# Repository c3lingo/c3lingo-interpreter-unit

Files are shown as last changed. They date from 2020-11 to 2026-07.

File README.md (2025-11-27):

# Conference Interpreter Unit
[c3lingo.org](https://c3lingo.org) is doing the great job of translating many talks of the Chaos Communication Congress and other CCC-related events to multiple languages.
But the required hardware for simultaneous translation is quite expensive to rent, even if it's "just" a specialized analog audio mixer.

So the idea was born to design an easy to use hardware with the special requirements of our interpreters in mind.

## Requirements
The hardware unit should deliver the native audio (stage/ hall mix) to the interpreter's headset and provide a sum of all interpreter's microphone to the input of the video streaming/ recording chain.
Mixing of the final translated audio (ducking the native audio with the translation) will be done as part of the streaming/ recording chain, so the interpreter unit should just provide the sum of all microphones.

Normally just 2 interpreters will provide one translation, but demanding talks might require 3 people.
So either 3 headphone inputs/ outputs should be provided or it must be possible to daisy-chain multiple units.

The user interface of the unit should be as simple, as possible to decrease the risk of mis-configuration.
This means, that no compressor and equalizer will be added in the input group.

General requirements:
- Line input of stage/ hall mix (native language) (XLR/ 6.3 mm balanced jack combo connector)
- 3x Microphone input (XLR) (at first just dynamic microphones)
    * VU-Meter for each input channel. (Perhaps with special color scheme: too quiet, good, too loud, clipping)
    * Fader/ Potentiometer for gain control
    * On-Air switch (on/ off position, with state LED)
    * Temporary mute button (momentary switch)
- 3x Headphone output (6.3 mm mono/ stereo (2x mono) jack)
    * Should output mix of native audio, own microphone and other translator's microphone
    * Potentiometer for output volume
    * Potentiometer for volume of own microphone in the mix
    * Potentiometer for volume of other two microphones in the mix
- Outputs:
    * Sum of all translators (XLR/ 6.3 mm balanced jack combo connector)

All inputs (besides the microphones) and outputs should:
- expect/ deliver a nominal level of +6dBu (~1.5 V RMS/ 4.3 V (p-p), german TV broadcast standard, 0 dBu = 0.775 V RMS)
- be transformer balanced and galvanically isolated

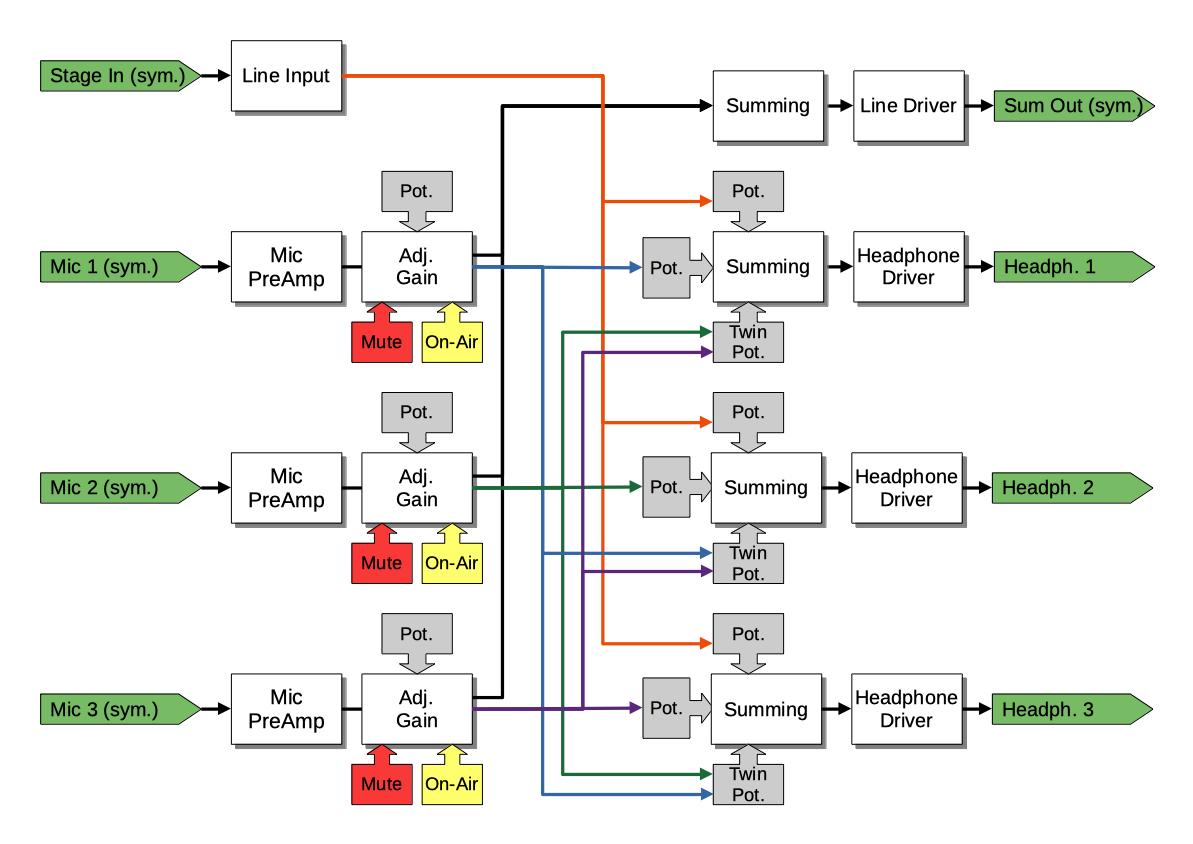
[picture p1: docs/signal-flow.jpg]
This results in a signal flow like this: 

## Status

### Tasks
- [x] Requirements collection
- [x] Electrical design draft/ proof of concept (breadboard)
- [x] Proof of concept validation
- [x] First PCB layout (prototyping modules)
- [x] More testing/ validation
- [x] Second PCB layout + casing prototype
    * [x] Channel strip schematic and PCB design
    * [x] Line I/O schematic and PCB design
    * [x] Power supply
- [x] More testing/ validation

Help is always appreciated!

### Implemented Requirements
- [x] Microphone input
- [x] Line input
- [x] Microphone summing and line output driver
- [x] Adjustable headphone mix and output volume
- [ ] ESD protection of line inputs and outputs
- [x] VU meter (own PCB)
- [x] VU meter (integrated in front panel PCB)
- [x] Mute and On-Air buttons

## Electrical Design
See [electrical-design.md](electrical-design.md).

Components marked as DNP (do not populate) are needed and need to be added.
The mark is just to generate the right BOM for ordering an assembled PBC with all SMD components, but no though-hole parts.

## User Interface
The user interface should enable the interpreters to adjust their microphone gain and headphone mix on their own.
Additionally, a (permanent) on/off switch, as well as a (temporary) mute button should be present.

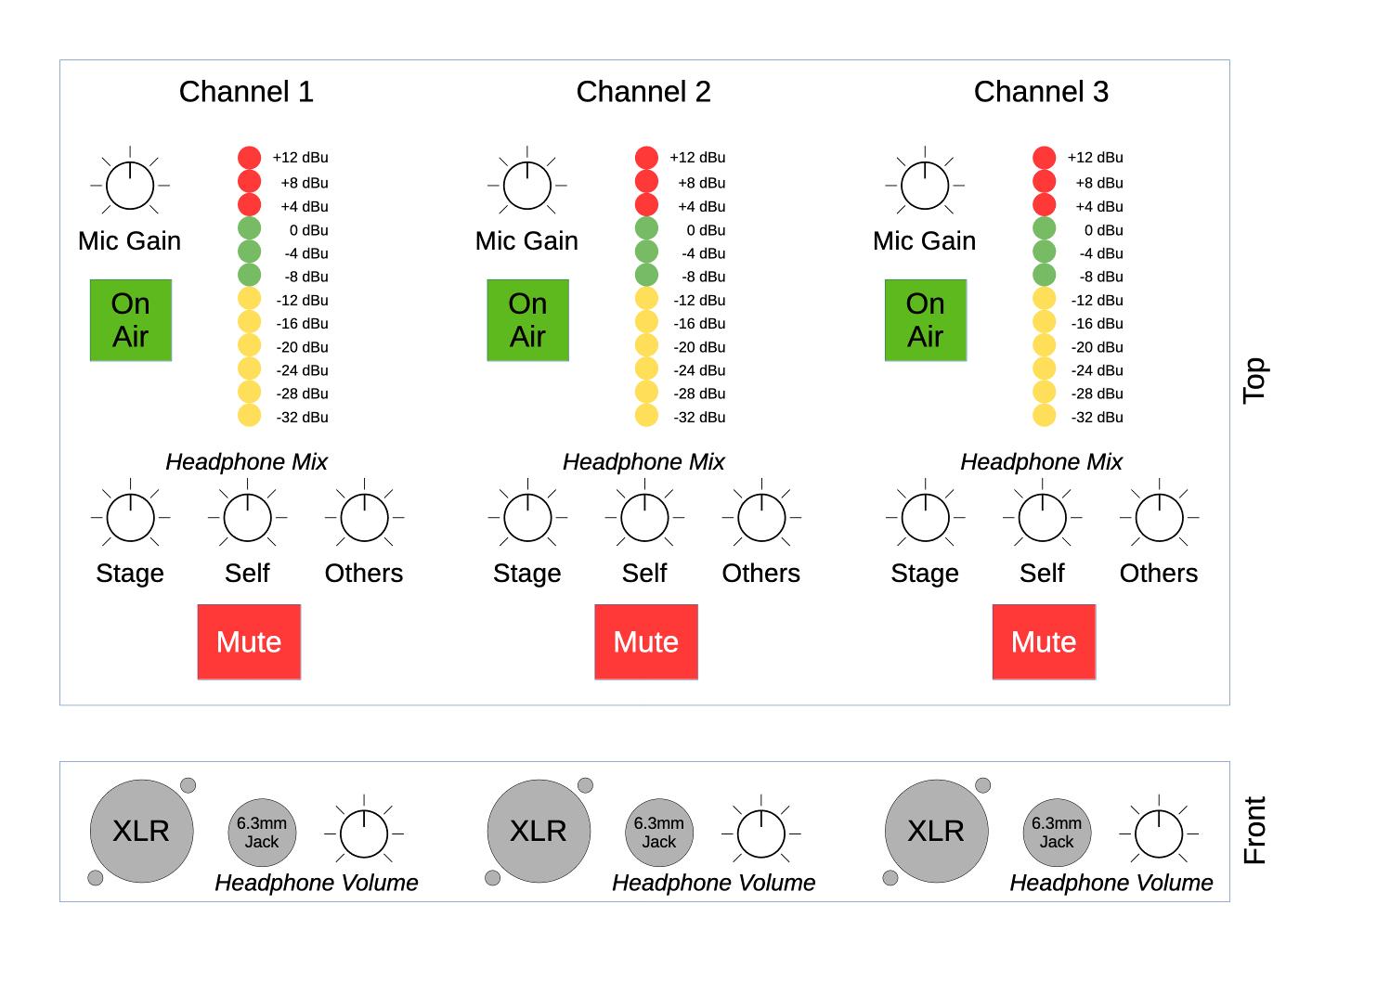
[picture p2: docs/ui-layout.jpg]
A possible UI layout might look like this: 

See [hardware-selection.md](hardware-selection.md) for the selection of potentiometers and switches.

### Casing
The casing should be a desk console (angled surface), ideally with space at the front to mount the headset ports (XLR and 6.3 mm jack).
Since it can be quite difficult to drill holes and make the appropriate cutouts on the angled surface, we designed our own housing from bent sheet metal.
See the [mechanical/](mechanical/README.md) directory for additional information.

PCBs are split up by channel and mounting surface, so that dimensional tolerancen between the surfaces are not that critical.
The top plate should have a maximum thickness of 1.5 mm, the front and back can be slightly thicker at 2 mm.
All LEDs need to be mounted with some space to the PCB surface so that they can cover the 9 mm gap to the front plate and still stick through.
A mounting guide can be found at [mechanical/assembly-helpers](mechanical/assembly-helpers/vumeter-leds.scad).

## Notes
A dynamic microphone needs at least 50-60 dB gain in the pre-amp, because a typical signal is at about 1 - 100 uV (-118 to -78 dBu or -120 to -80 dBV).

Line level in professional audio gear is at +4 dBu, which is 1.228 V (RMS).
Because 0 dBu is defined as 1 mW at a load of 600 Ohm, which needs a voltage of 0.77 V.
Increasing the voltage by a factor of 10 is an amplification of 20 dB.

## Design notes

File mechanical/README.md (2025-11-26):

# Housing and 3D Printed Parts

## Housing
The housing is made from bend sheet metal and designed in FreeCAD.

### Requirements
- FreeCAD 1.x with SheetMetal Workbench Addon installed

## Assembly Helpers
To place the level meter (aka. VU meter) LEDs at the needed height, an assembly helper is available at [./assembly-helpers/vumeter-leds.scad](./assembly-helpers/vumeter-leds.scad).

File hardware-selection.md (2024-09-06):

# c3lingo Unit -- Knobs and Switches
Detailed information why certain knobs (potentiometers) and switches were chosen.

## Potentiometers
We need some single logarithmic scale potentiometers, which are matching in size, for:

- top plate interface (all vertical style, threaded collar would be nice):
    * 1 50k single channel for the input gain
    * 3 50k single channel for the headphone mix
- front plate next to the headset jacks (horizontal style, threaded collar not needed):
    * 1 50k single channel for the headphone volume

Possible knobs may be:

- for D-style (6 mm diameter, flattened to 4.5 mm) and 18-teeth spline (6 mm diameter) axle:
    - (A) Re'an F311 series (11 mm diameter):  
        Boring: 9.0 mm D-style hole + 0.0 mm nut cover section = 9.0 mm
- for D-style (6 mm diameter, flattened to 4.5 mm) axle:
    - (B) Re'an P670 series (12 mm diameter/ 16 mm at bottom) (alt. Davies Molding 1101):  
        Boring: 7.5 mm D-style hole + 4.5 mm nut cover section = 12.0 mm  
        Nut cover: 12.9 mm diameter (M7 nut is 12.5 mm corner to corner)
    - (C) Re'an P300 series (11 mm diameter/ 15 mm at bottom):  
        Boring: 9.0 mm D-style hole + 3.0 mm nut cover section = 12.0 mm  
        Nut cover: ? mm diameter (M7 nut is 12.5 mm corner to corner)
- for 18-teeth spline (6 mm diameter) axle:
    - (D) Davies Molding 1106-A (blue)/ 1106-WA (white) (13-18 mm diameter):  
        Boring: 14.2 mm 18-teeth hole + 2.5 mm nut cover section = 16.7 mm  
        Nut cover: ? mm diameter
    - (E) Davies Molding 1101-A (11 to 16 mm diameter):  
        Boring: 8.0 mm 18-teeth hole + 4.1 mm nut cover section = 12.1 mm  
        Nut cover: ? mm diameter

Vertical (pins on bottom):

- Metal 18 teeth style:
    - CUI Devices PTN091-V50115K1A
        * 7.4 mm mounting height
        * M7x0.75 thread, 5 mm high
        * 15 mm (incl. collar thread) long 18-teeth 6 mm diameter knurled shaft with slit
        * A-taper (log) 50k
        * Datasheet: https://www.cuidevices.com/product/resource/ptn09x.pdf
        * Knobs (see above): _D_
    - Alpha RD901F-40-15K-A50K https://www.taydaelectronics.com/potentiometer-variable-resistors/rotary-potentiometer/logarithmic/50k-ohm-logarithmic-taper-potentiometer-knurled-plastic-spline-sha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
        * 10 mm mounting height
        * M9x0.75 or M7x0.75 thread, 5 mm high?
        * 15 mm (incl. collar thread) long 18-teeth 6 mm diameter knurled shaft with slit
        * A-taper (log) 50k
        * Datasheet: https://www.taiwanalpha.com/downloads?target=products&id=113
        * Notes: Hard to get
    - Bourns PTV09A-4020S-A503
        * 8.0 mm mounting height
        * no collar/ threads
        * 12 mm long 18-teeth 6 mm diameter knurled shaft with slit
        * A-taper (log) 50k
        * Datasheet: https://www.bourns.com/docs/Product-Datasheets/PTV09.pdf
- D-type shaft:
    - Bourns PTV09A-4015F-A503
        * 8.0 mm mounting height
        * no collar/ threads
        * 7 mm long D-style 6 mm diameter shaft (6 mm of which flattened)
        * A-taper (log) 50k
        * Datasheet: https://www.bourns.com/docs/Product-Datasheets/PTV09.pdf
    - Bourns PTV111-4420A-A503
        * 8.5 mm mounting height
        * no collar/ threads
        * 12 mm long D-style 6 mm diameter shaft (7 mm of which flattened)
        * A-taper (log) 50k
        * Datasheet: https://www.bourns.com/docs/Product-Datasheets/PTVPTT.pdf

Horizontal (shaft to the side):

- D-type shaft:
    - Alps Alpine RK09K1110B1R:
        * axle 10 mm above PCB
        * no collar/ threads
        * 7.4 mm long D-style 6 mm diameter shaft (6 mm of which flattened)
        * A-taper (log) 50k
        * Datasheet: TODO
        * Knobs (see above): _A_

**Selection**:

- Channel Mixer (input gain and mix):
    * CUI Devices PTN091-V50115K1A + Davies Molding 1106-A
- Headphone volume:
    * RK09K1110B1R (single, 50K, 15 mm) + Re'an F311

## Switches
The **On-Air** button needs to be a latching DPDT switch (TODO: not true any more, can also be single pole), ideally with LED illumination and max. 8 mm height (PCB to front plate), like:

- E-Switch TL2230EEF140, no illumination -- 0.60 €  
    DPDT, PCB mount  
    Height: 7.0 mm + 5.5 mm plunger (2x3 mm cap terminal)  
    Cap: see APEM models
- **APEM MHPS2273 (EU version: PHAP4673), no illumination, no audible click -- 0.41 €**  
    DPDT, PCB mount  
    Height: 7.0 mm + 5.5 mm plunger (2x3 mm cap terminal)  
    Cap: U542x (11.5 mm square, 4 mm height), **U453x (9.4 mm dia., 6.65 mm height) -- 0.64 €**  
    Cap color codes: **2 Black**, 4 Grey, 5 Yellow, 6 Red

The **mute** button needs to be a momentary SPST (normally open) or SPDT push button, like:

- E-Switch TL2230OAF140, no illumination -- 0.53 €  
    DPDT, PCB mount  
    Height: 7.0 mm + 5.5 mm plunger (2x3 mm cap terminal)  
    Cap: see APEM models
- **APEM 1413NC6/ 1415NC6 -- 3.72 €**  
    SPST/ SPDT, front plate snap-in mount, solder lugs  
    Button size: 12 mm square, Color: Red (color code 6)  
    Cap: U542x (11.5 mm square, 4 mm height), **U453x (9.4 mm dia., 6.65 mm height) -- 0.64 €**  
    Cap color codes: 2 Black, 4 Grey, 5 Yellow, 6 Red  
    Depth: 13 mm + 6 mm for contacts = 19 mm
- NKK Switches LP0115C{C,M}KW01-C -- 7.91 €  
    SPDT, front plate bushing/ snap-in mount, solder lugs  
    Button size: 13.6 mm dia., Color: Red (color code C)  
    Depth: 22 mm

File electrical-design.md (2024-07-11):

# c3lingo Unit -- Electrical Design
This file contains some notes on the electrical design.
Currently just the sources of the used circuit designs.

## Microphone Input
### Preamplifier
For the microphone preamp, we are using the NE5534 low-noise opamp with a circuit design from circuitlib.com (29-balanced-microphone-preamplifier).

### Controllable Amplification
In a normal mixer, you would be able to lower the microphone's volume to zero.
But in our case we just need on/ off and some gain range to adjust for different microphones and loudness of different people.

## Line Input/ Input Module
The line input must not be amplified at all, because loudness control of the headphones is done by the headphone amplifier section.
But the differential line-level signal must be converted to a single-ended signal by the input stage.

The current design uses a LM833-N opamp to convert the balanced signal into a single ended signal and has a second LM833-N to provide some degree (+- 6 dB) of "factory" adjustment.
The second part of that circuit was taken from the circuitlib.com audio mixer tutorial (39-how-to-build-an-audio-mixer).

## Summing
Summing is needed in two places: Creating the sum of all microphones (not adjustable, fixed output gain) and for the headphone mix (one input level adjustable).
A simple summing circuit using one operational amplifier is enough for our application.

The mixer design uses inverting op-amp circuits, because they require less components and signal routing.
Normally an audio mixer should take care of adding signals in-phase, because otherwise two microphones might cancel each other out.
In our case, there are just two types of summing: All microphones for the interpreter unit's line-out and the individual headphone mixes.
Because the stage input is quite independent of the interpreter's microphones, no special phase/ inversion considerations are needed.
And the microphones connected to our unit will experience the same inversions anyways.

## Line Output Driver
Line Output conversion is done by the [DRV134](https://www.ti.com/product/DRV134) IC.

## Headphone Output Driver
The headphone output needs a maximum output power of about 100 mW and should put the mono signal on both stereo channels of the TRS jack.
For example the DT 700 Pro (250 Ohms) need about 63 mW (4 V RMS, 16 mA), which seems to be the worst required voltage of all headphones (and not actually possible at 5V supply voltage).
Since the whole channel is desinged to use 0 dBu as target, the headphone amp needs to have an amplification of up to 5.

~~For the first draft, we're using one LM386 audio power amplifier even though it has a quite high minimal amplification of factor 20.~~
A better headphone amp seems to the the TI TPA6111A2.

## VU Meter
When searching for VU meter circuits, many use the LM3916 LED bar graph driver, which already has the right scaling built in.
But this chip is obsolete and not produced any more, so we designed our own chain of comparators to drive a set of LEDs.

## Phantom Power
The cheap but still decent Superlux HMC-660 headset is known to sound quite bad with standard 48 V phantom power (which can be easily fixed by adding some resistors inside the XLR connector).
But when I bought one in April 2021, it worked just fine with 48 V and didn't really work with 12 or 15 V.
So, if phantom power should be a feature of the interpreter unit, it probably best to have standard 48 V instead of any special treatment for one special headset.

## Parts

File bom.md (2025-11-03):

# Bill of Materials

List of major components (resistors and capacitors are left out).

All prices without VAT unless otherwise noted and without discount for higher order volume.

## Power Supply
When 48V phantom power is not urgently needed, just use a Mean Well RT-50C power supply to provide +15V, -15V and +5V.
Otherwise a way to create clean 48V from one of these power rails is needed, but we want to only use dynamic microphones anyways.

## Housing
All components fit in the off-the-shelf Hammond Manufacturing 1456PH3 housing.
But drilling and routing the holes in already bent metal sheets may be difficult

### Custom Housing
The Design is based on the Hammond Manufacturing 1456PH3 with a reduced width and increased hight of the Channel I/O Section

| Count | Manufacturer + Art. No. | Description | Distributor Order No.
|---|---|---|---
| 1 | Housing Shell | Aluminium Sheet 1.5mm | _custom made_
| 1 | Housing Bottom | Aluminium Sheet 2mm | _custom made_
| 4 | 2.9x9.5 ISO 7049 (PZ) | Self Tapping Screw (for feet) | Wegertseder 4003-317 (alt. ISO 14585 (TX) 4671-006)
| 4 | M3x10 ISO 7045 (PH) | M3x10 Pan Head Screw (alt. for feet) | Wegertseder 1118-038 (alt. ISO 14583 (TX) 3840-514)
| 4 | Rubber Feet 14x11x9mm D3  | Rubber Feet 14x11x9mm D3 | Aliexpress 1005006347586608
| 2 | PEM FH-M4-10ZI. | PEM M4 Stud 10mm | Mouser 153-FH-M4-10ZI, eBay
| 2 | Wegertseder 1776-794 | M4 Kontaktscheibe (for grounding) | Wegertseder 1776-794
| 2 | M4 DIN 6923 | M4 Hex Nut with toothed Flange (gnd.) | Wegertseder 3995-101
| 3 | _generic_ | Ring Cable Lug 0.75 mm2 (for grounding) | Voelkner D28838
| 2 | M3x5 ISO 7380 | M3x5 Flat Head Screw (for power supply) | Wegertseder 2570-578
| 2 | M3x10 ISO 14581 (TX) | M3x10 Counter Sunk Screw (for C14 socket) | Wegertseder 4663-108 (alt. ISO 7046 (PZ) 4456-239)
| 2 | M3 DIN 934 | M3 Nut (for C14 socket) | Wegertseder 2888-006

## Boards
The PCBs with all SMD components cost about 40€ per console (depending on order volume and shipping option).
Additional components like power supply, connectors, etc. add up to about 100€ per console.

### Line I/O Board Components
BOM for one PCB, needed 1x for whole assembly.
Electrolytic capacitors should have 25 V voltage rating, unless otherwise specified.

| Count | Manufacturer + Art. No. | Description | Distributor Order No.
|---|---|---|---
| 1 | Neutrik NCJ6FA-H | Stage Line Input | Voelkner D21915, Thomann 250931
| 1 | Neutrik NC3MAAH | Mix Line Output | Voelkner X39973, Mouser 568-NC3MAAH
| 1 | SPTAF 1/ 4-3,5-EL | PCB PowerSupply | Mouser 651-1862068
| 3 | WE WR-BHD 61201021621 | IDC socket, Interconn. to channel | Mouser 710-61201021621
| 1 | CTS 195-2MST | DIP switch vertical | Mouser 774-1952MST
| 1 | Keystone test point 5006  | TEST POINT BLK .063 | Mouser 534-5006
| 1 | Mean Well RT-50C | Power Suppy | Voelkner A246532
| 1 | TC-10475840 | IEC C14 Socket, screwed, M3, 40mm | Voelkner X960872 (alternative. D28684)
| 1 | LM833-N | Generic Op-Amp | JLC C473907 (usually ordered with PCB assembly)
| 1 | DRV135UA | Line Driver | JLC C431073 (usually ordered with PCB assembly)

#### Channel Strip Components
BOM for one PCB, needed 3x for whole assembly.
Electrolytic capacitors should have 25 V voltage rating, unless otherwise specified.

| Count | Model or Art. No. | Description | Distributor Order No.
|---|---|---|---
|  1 | Neutrik NC3FAAH2 | Microphone Input | Voelkner X39703, Mouser 568-NC3FAAH-2
|  1 | Rean NYS 216 or 216G | Headphone Output | Mouser 568-NYS216-U
|  1 | WE WR-BHD 61201021721 | Mix Interconn. to Line I/O, horiz.| Mouser 710-61201021721
|  2 | WE WR-BHD 61200821721 | Mix Interconn. w/ Ch. I/O, horiz. | Mouser 710-61200821721
|  1 | BKL 10120667 | IDC cable 8-pole, 25cm | Reichelt
|  1 | BKL 10120668 | IDC cable 10-pole, 25cm | Reichelt
|  1 | Molex 22-28-8024 | Pin header to Mute btn. , horiz.  | Mouser 538-22-28-8024
|  4 | CUI PTN091-V50115K1A | 50K log. (vert.) Heads. Mix +Gain | Mouser 179-PTN091V50115K1A
|  1 | Alps RK09K1110B1R | 50K log. (horiz.) Vol. | Mouser 688-RK09K1110B1R
|  3 | Davies Molding 1106-WA | Potentiometer Knob f. Mix (star)  | Mouser 5164-1106-WA
|  1 | Davies Molding 1108 | Potentiometer Knob f. Vol. (D) | Mouser 5164-1108
|  1 | Cliff CL170842CR (red) | Potentiometer Knob f. Gain (star) | Voelkner D71805
|  1 | APEM MHPS2273 | OnAir Switch | Mouser 642-MHPS2273
|  1 | APEM MH15 (alt. U4535) | On-Air Button yellow cap | Mouser 642-MH12
|  1 | Adafruit 3430 | Adafruit Arcade button (red) | Mouser 485-3430
|  3 | Kingbright WP113GDT | 2x5mm Rectangular LED, green | Mouser 604-WP113GDT (alternative: 859-LTL-433G)
|  6 | Kingbright WP113YDT | 2x5mm Rectangular LED, yellow | Mouser 604-WP113YDT (alternative: 859-LTL-433Y)
|  3 | Kingbright WP113IDT | 2x5mm Rectangular LED, red | Mouser 604-WP113IDT (alternative: 859-LTL-433HR)
| 12 | Fischer RAH 504 | 4mm spacer, square | Reichelt FIS RAH 504
|  1 | Kingbright WP710A10LID | 3mm diffused LED, red | Mouser 604-WP710A10LID
|  1 | Fischer MAH 308 | 8mm spacer, 3mm round | Reichelt FIS MAH 308
|  3 | LM339 | Quad Diff. Comparators | JLC C7948 (usually ordered with PCB assembly)
|  1 | LM833-N | Generic Op-Amp | JLC C473907 (usually ordered with PCB assembly)
|  1 | NE5534 | Low-noise bipolar Op-Amp | JLC C9916 (usually ordered with PCB assembly)
|  1 | TL072{C,I,HI}DR | Low-noise FET Op-Amp | JLC C67473 (usually ordered with PCB assembly)
|  1 | TPA6111A2 | Headphone Amp | JLC C497472 (usually ordered with PCB assembly)
|  7 | 1N4148 | Signal Diode SOD-123 | JLC C7420318 (usually ordered with PCB assembly)
|  1 | J113 | SMD J-FET SOT-23 | JLC C891686 (usually ordered with PCB assembly)

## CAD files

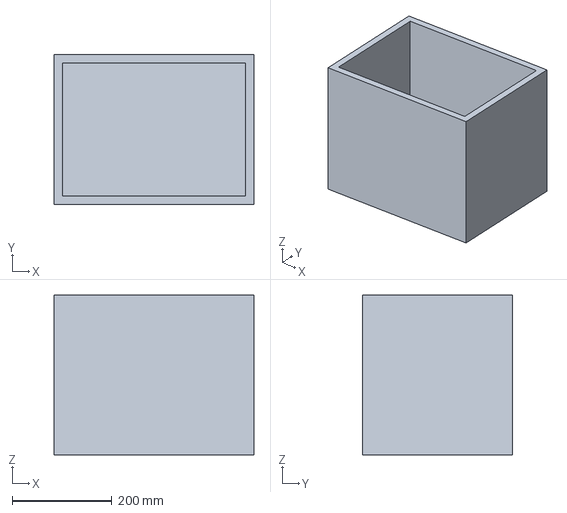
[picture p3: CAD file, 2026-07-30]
crate.FCStd
400.0 x 300.0 x 320.0 mm

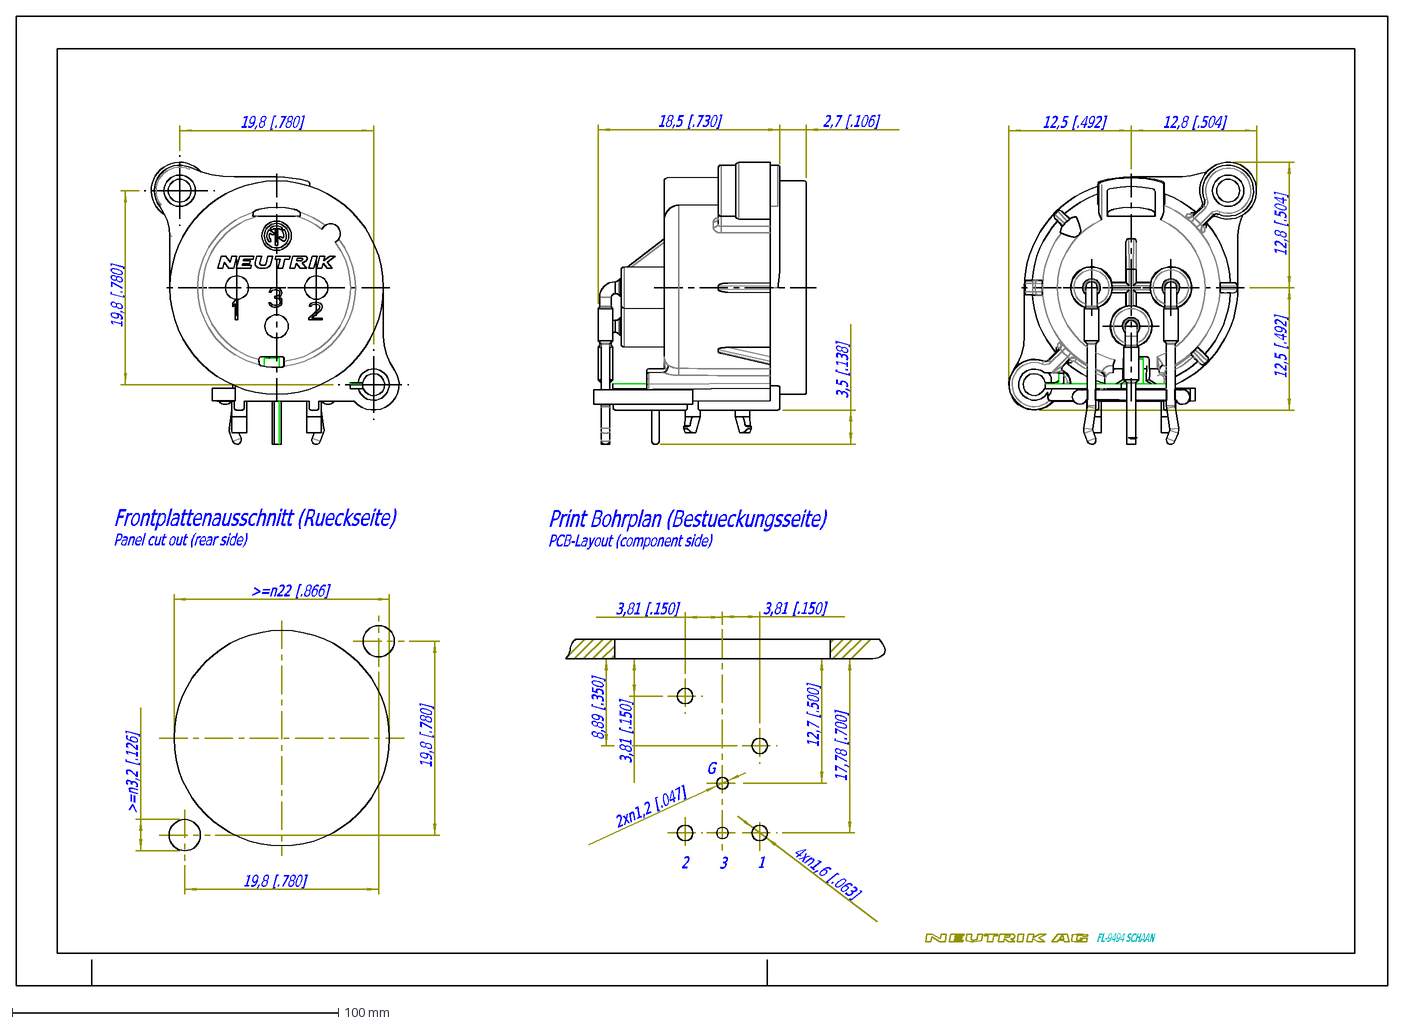
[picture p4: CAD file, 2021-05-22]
docs/datasheets/Neutrik-nc3maah.dxf
FL-9494 SCHAAN
19,8 [.780]
12,5 [.492]
3,5 [.138]
3,81 [.150]
8,89 [.350]
12,7 [.500]
17,78 [.700]
2,7 [.106]
12,8 [.504]
18,5 [.730]
Frontplattenausschnitt (Rueckseite) Panel cut out (rear side)
G
2
3
1
Print Bohrplan (Bestueckungsseite) PCB-Layout (component side)

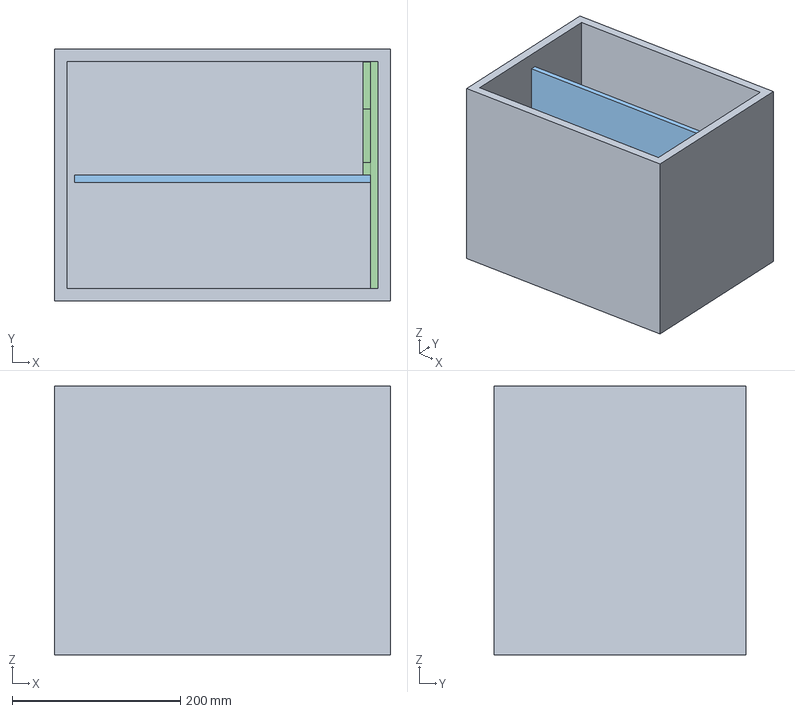
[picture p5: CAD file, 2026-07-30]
mechanical/eurocrate-inlay.FCStd
400.0 x 300.0 x 320.0 mm
Auer ED 4332
Side
Divider
Rails

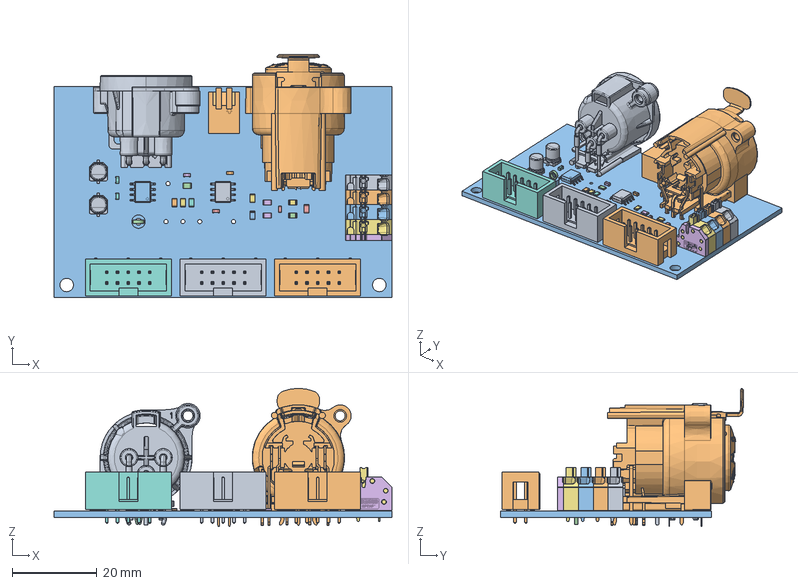
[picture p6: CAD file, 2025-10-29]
mechanical/pcba-3d/c3lingo_unit-mix_io.FCStd
80.0 x 57.6 x 32.8 mm
Jack_XLR_Neutrik_NC3MAAH_Horizontal
Jack_XLR-6.35mm_Neutrik_NCJ6FA-H_Horizontal
Bohrloch.1.1
Bohrloch.1.002
Bohrloch.2
Bohrloch.003
Bohrloch.1.003
Bohrloch.004
SPTAF_1-3.5_housing
SPTAF_1-3.5_housing001
SPTAF_1-3.5_housing002
Bohrloch.005
Bohrloch.1.004
SPTAF-0-DKL.1
SPTAF_1-3.5_housing003
IDC-Header_2x05_P2.54mm_Vertical
IDC-Header_2x05_P2.54mm_Vertical001
R_0805_2012Metric
R_0805_2012Metric001
R_0805_2012Metric002
R_0805_2012Metric003
R_0805_2012Metric004
R_0805_2012Metric005
C_0603_1608Metric
SOIC-8_3.9x4.9mm_P1.27mm
IDC-Header_2x05_P2.54mm_Vertical002
SOIC-8_3.9x4.9mm_P1.27mm001
R_0805_2012Metric006
C_0603_1608Metric001
R_0805_2012Metric007
R_0805_2012Metric008
C_0603_1608Metric002
CP_Elec_4x5.4
C_0603_1608Metric003
TestPoint_Keystone_5005-5009_Compact
TestPoint_Keystone_5005-5009_Compact001
C_0603_1608Metric004
C_0603_1608Metric005
R_0805_2012Metric009
R_0805_2012Metric010
CP_Elec_4x5.005
SW_DIP_SPSTx02_Piano_CTS_Series194-2MSTN_W7.62mm_P2.54mm
c3lingo_unit-mix_io_PCB

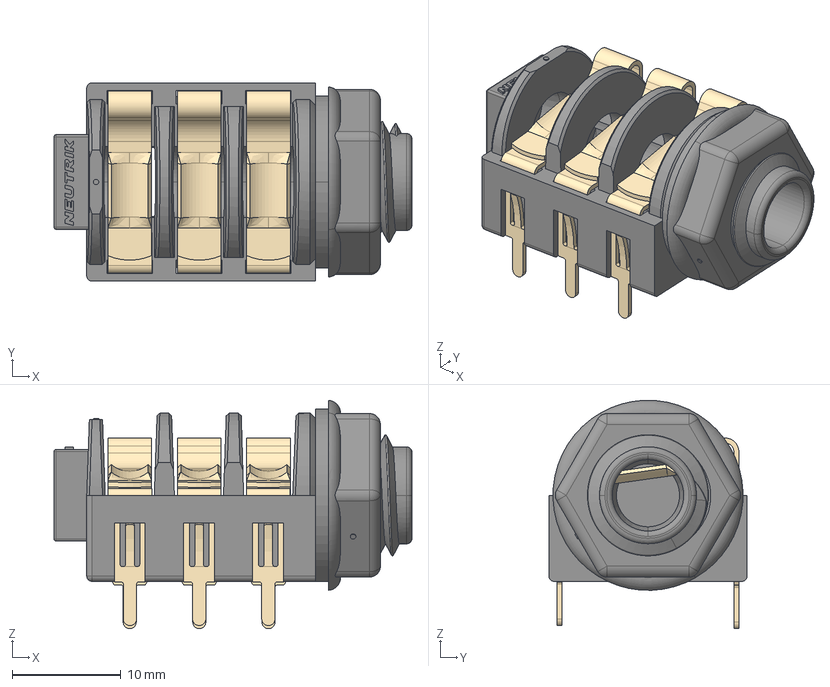
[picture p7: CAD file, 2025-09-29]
schematics/c3lingo_unit-assembly/kicad-libraries/c3lingo_unit-3dmodels/Jack_6.35mm_Neutrik_NMJ6HFD2_Horizontal.step
32.9 x 18.2 x 21.0 mm

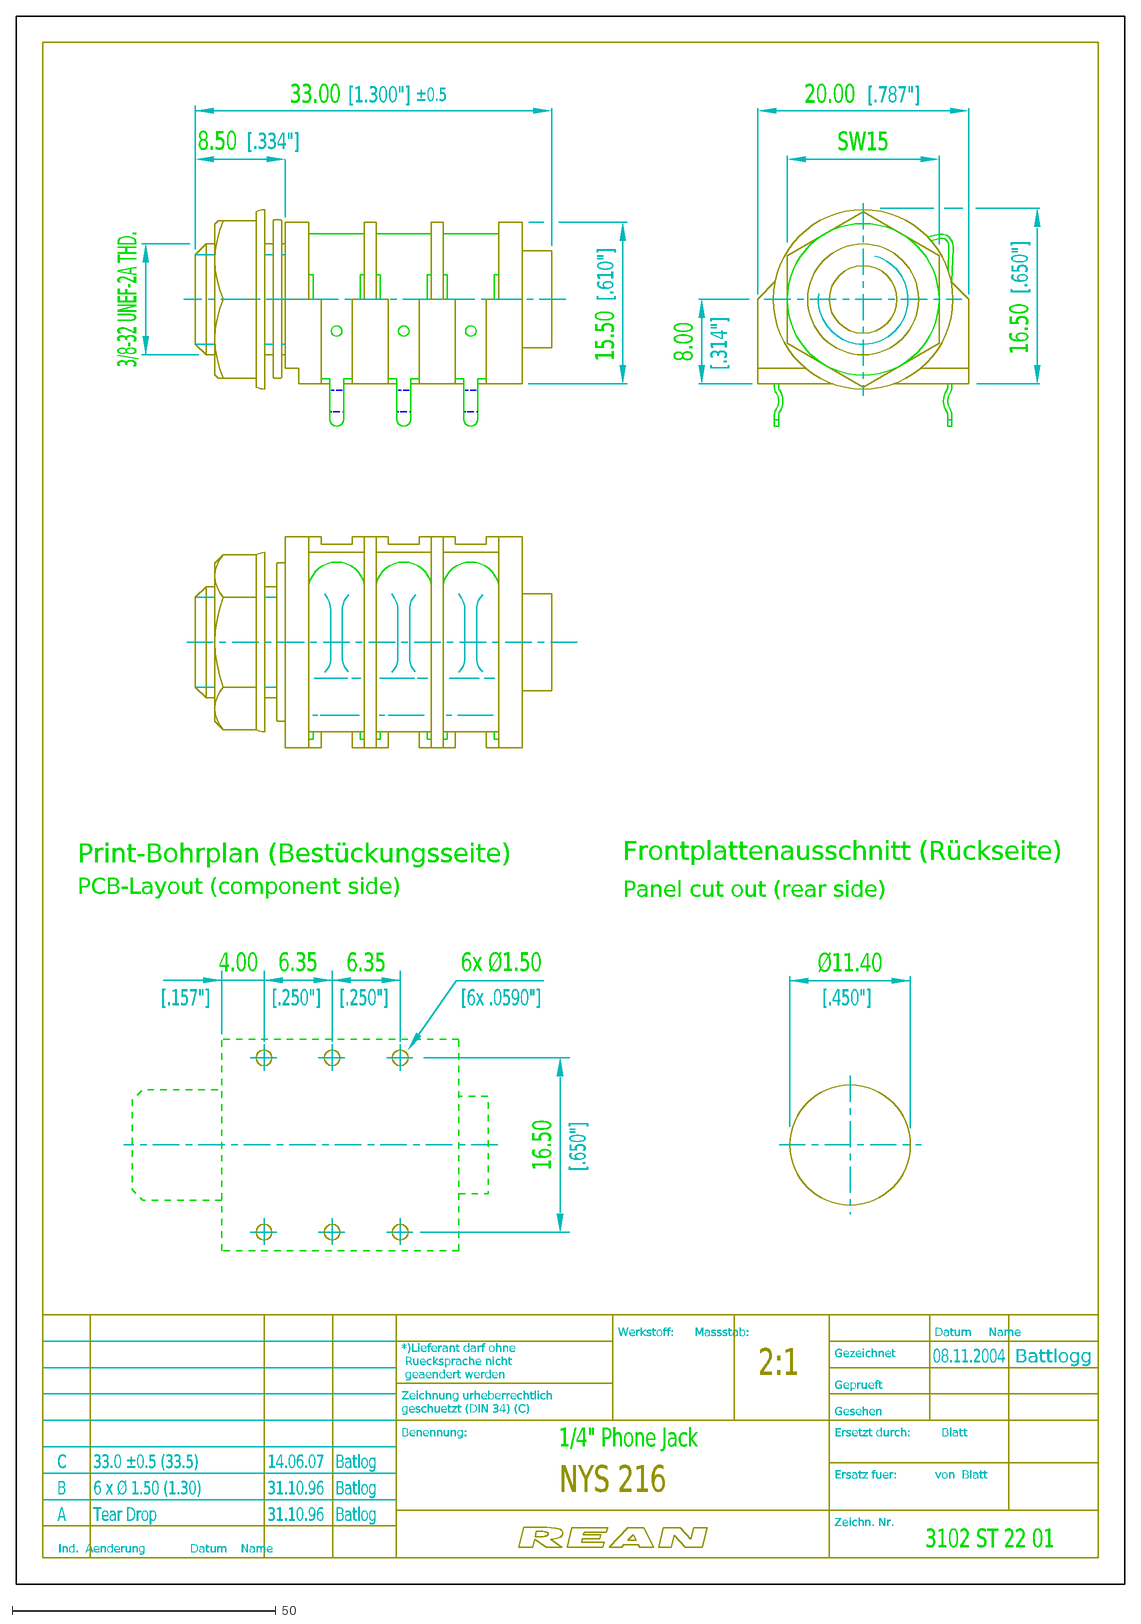
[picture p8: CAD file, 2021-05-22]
docs/datasheets/NeutrikRean-nys216.dxf
8.50
33.00
20.00
8.00
15.50
3/8-32 UNEF-2A THD.
[1.300"]
[.334"]
[.787"]
[.314"]
[.610"]
[.650"]
16.50
6.35
[.250"]
[.157"]
4.00
[6x .0590"]
6x Ø1.50
Ø11.40
[.450"]
SW15
PCB-Layout (component side)
Print-Bohrplan (Bestückungsseite)
Panel cut out (rear side)
Frontplattenausschnitt (Rückseite)
Battlogg
08.11.2004
NYS 216
1/4" Phone Jack
3102 ST 22 01
2:1
A
Tear Drop
31.10.96
Batlog
B
6 x Ø 1.50 (1.30)
C
33.0 ±0.5 (33.5)
14.06.07
Zeichn. Nr.
Ersetzt durch: Blatt
Gezeichnet
Gesehen
Datum Name
Werkstoff: Massstab:
Benennung:
*)Lieferant darf ohne
Ruecksprache nicht
geaendert werden
Zeichnung urheberrechtlich
geschuetzt (DIN 34) (C)
Geprueft
Ersatz fuer: von Blatt
Ind. Aenderung Datum Name
±0.5

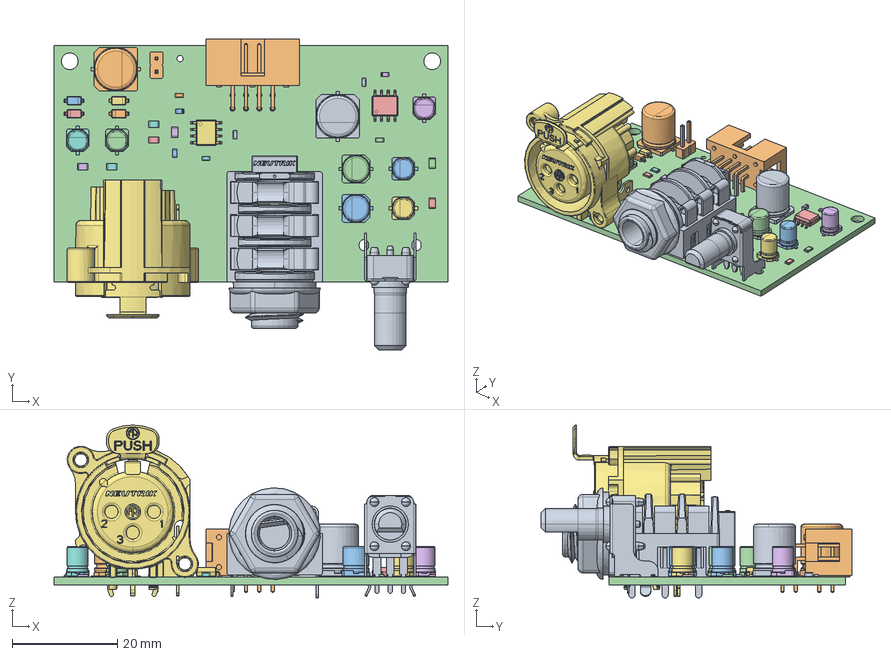
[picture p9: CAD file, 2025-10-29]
mechanical/pcba-3d/c3lingo_unit-channel_io.FCStd
75.0 x 59.2 x 32.9 mm
Jack_6.35mm_Neutrik_NMJ6HFD2_Horizontal
C_0603_1608Metric
D_SOD-123
CP_Elec_4x5.8
R_0805_2012Metric
R_0805_2012Metric001
SOIC-8_3.9x4.9mm_P1.27mm
R_0805_2012Metric002
C_0603_1608Metric001
IDC-Header_2x04_P2.54mm_Horizontal
CP_Elec_4x5.009
R_0603_1608Metric
SOIC-8_3.9x4.9mm_P1.27mm001
CP_Elec_4x5.010
Jack_XLR_Neutrik_NC3FAAH2_Horizontal
C_0603_1608Metric002
Potentiometer_Alps_RK09K_Single_Horizontal
D_SOD-124
R_0603_1608Metric001
R_0805_2012Metric003
R_0805_2012Metric004
R_0805_2012Metric005
D_SOD-125
CP_Elec_4x5.011
CP_Elec_8x10
CP_Elec_8x011
R_0603_1608Metric002
CP_Elec_5x5.8
D_SOD-126
R_0603_1608Metric003
CP_Elec_4x5.012
R_0805_2012Metric006
C_0603_1608Metric003
PinHeader_1x02_P2.54mm_Vertical
CP_Elec_5x5.009
c3lingo_unit-channel_io_PCB

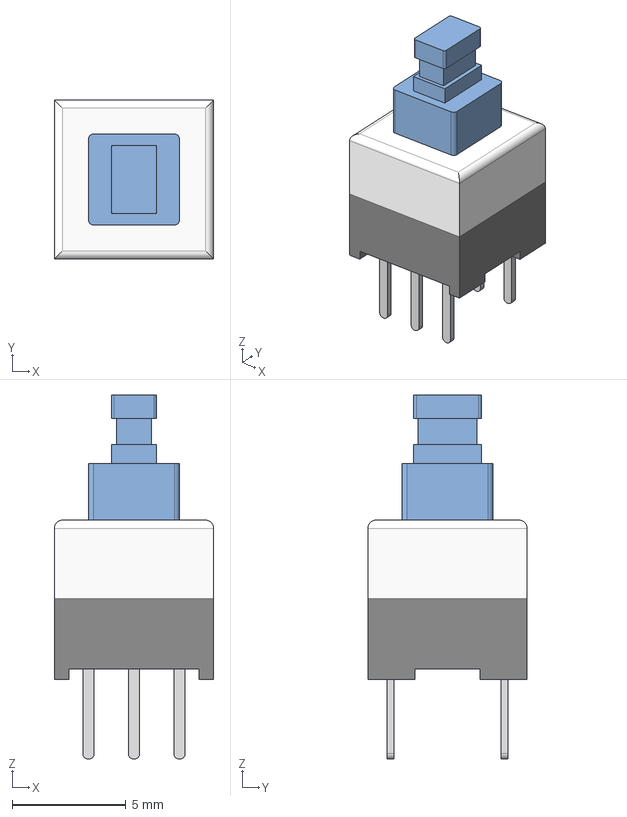
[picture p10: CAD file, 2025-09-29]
schematics/c3lingo_unit-assembly/kicad-libraries/c3lingo_unit-3dmodels/SW_APEM_MHPS2273_DPDT.step
7.00 x 7.00 x 16.0 mm

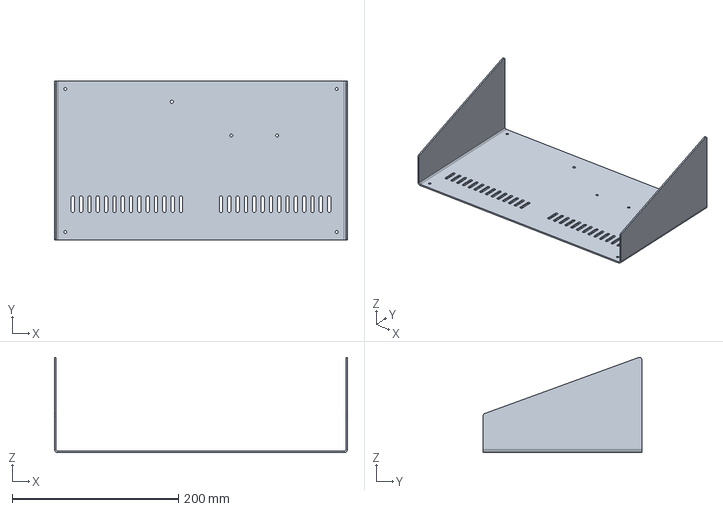
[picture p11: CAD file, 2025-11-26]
mechanical/c3lingo-interpreter-unit_housing_bottom.FCStd
352.0 x 191.0 x 114.5 mm

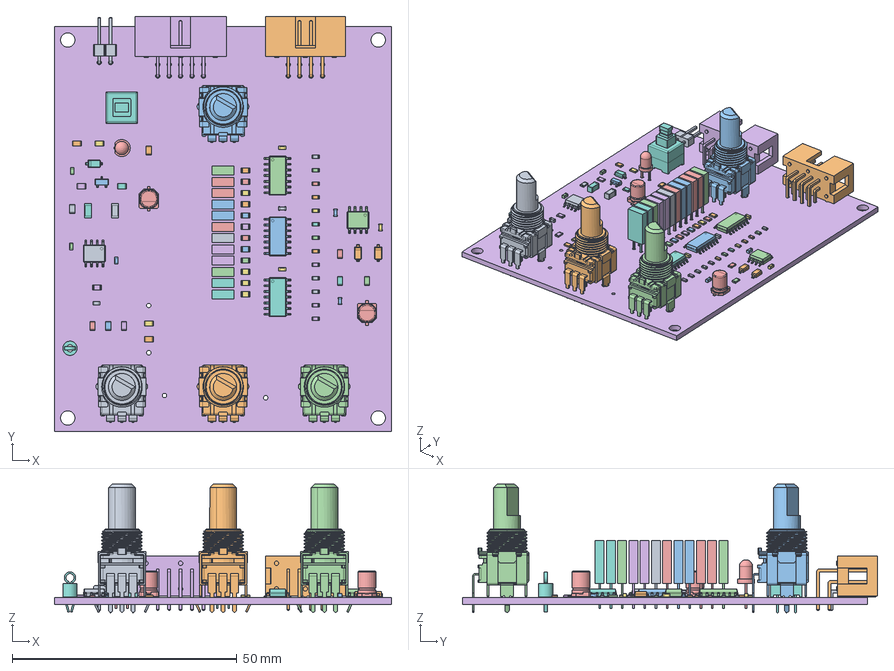
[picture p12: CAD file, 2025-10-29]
mechanical/pcba-3d/c3lingo_unit-channel_mixer.FCStd
75.0 x 92.2 x 28.6 mm
Potentiometer_Alps_RK09L1140_Single_Vertical
Potentiometer_Alps_RK09L1140_Single_Vertical001
Potentiometer_Alps_RK09L1140_Single_Vertical002
Potentiometer_Alps_RK09L1140_Single_Vertical003
LED_D3.0mm
IDC-Header_2x05_P2.54mm_Horizontal
R_0805_2012Metric
SW_APEM_MHPS2273_DPDT
R_0603_1608Metric
R_0805_2012Metric001
C_0603_1608Metric
C_0603_1608Metric001
R_0805_2012Metric002
R_0805_2012Metric003
R_0805_2012Metric004
TestPoint_Keystone_5005-5009_Compact
R_0805_2012Metric005
D_SOD-123
C_0603_1608Metric002
R_0603_1608Metric001
LED_Rectangular_W5.0mm_H2.0mm
R_0805_2012Metric006
C_0603_1608Metric003
LED_Rectangular_W5.0mm_H2.0mm001
C_0603_1608Metric004
R_0805_2012Metric007
SOIC-14_3.9x8.7mm_P1.27mm
LED_Rectangular_W5.0mm_H2.0mm002
LED_Rectangular_W5.0mm_H2.0mm003
LED_Rectangular_W5.0mm_H2.0mm004
R_0805_2012Metric008
R_0805_2012Metric009
R_0603_1608Metric002
R_0603_1608Metric003
LED_Rectangular_W5.0mm_H2.0mm005
C_0603_1608Metric005
R_0805_2012Metric010
LED_Rectangular_W5.0mm_H2.0mm006
C_0603_1608Metric006
LED_Rectangular_W5.0mm_H2.0mm007
PinHeader_1x02_P2.54mm_Horizontal
R_0805_2012Metric011
LED_Rectangular_W5.0mm_H2.0mm008
SOIC-8_3.9x4.9mm_P1.27mm
CP_Elec_4x5.8
R_0603_1608Metric004
R_0603_1608Metric005
C_1206_3216Metric
C_1206_3216Metric001
D_SOD-124
C_0603_1608Metric007
R_0603_1608Metric006
R_0805_2012Metric012
R_0805_2012Metric013
R_0805_2012Metric014
R_0805_2012Metric015
LED_Rectangular_W5.0mm_H2.0mm009
R_0805_2012Metric016
R_0805_2012Metric017
LED_Rectangular_W5.0mm_H2.0mm010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

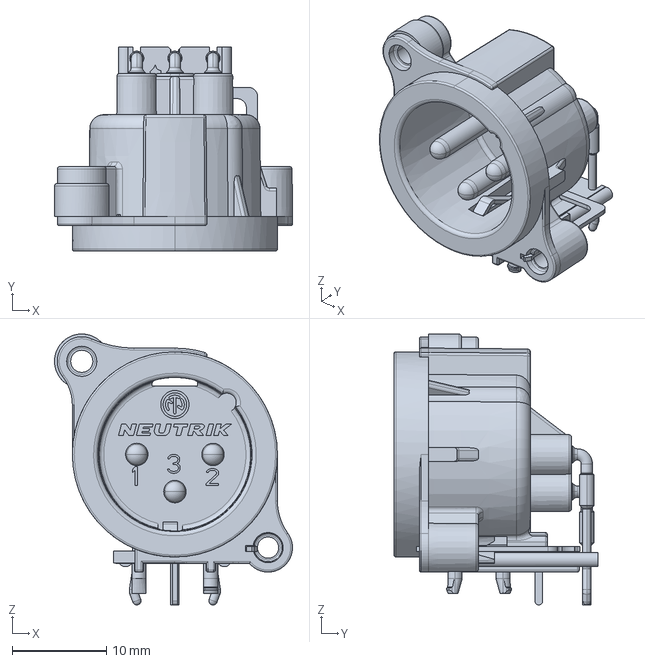
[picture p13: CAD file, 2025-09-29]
schematics/c3lingo_unit-assembly/kicad-libraries/c3lingo_unit-3dmodels/Jack_XLR_Neutrik_NC3MAAH_Horizontal.step
25.3 x 21.7 x 28.8 mm

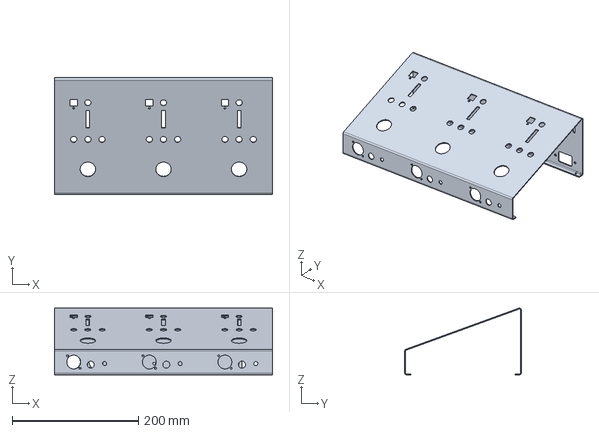
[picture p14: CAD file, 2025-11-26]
mechanical/c3lingo-interpreter-unit_housing_shell.FCStd
346.0 x 185.0 x 106.0 mm

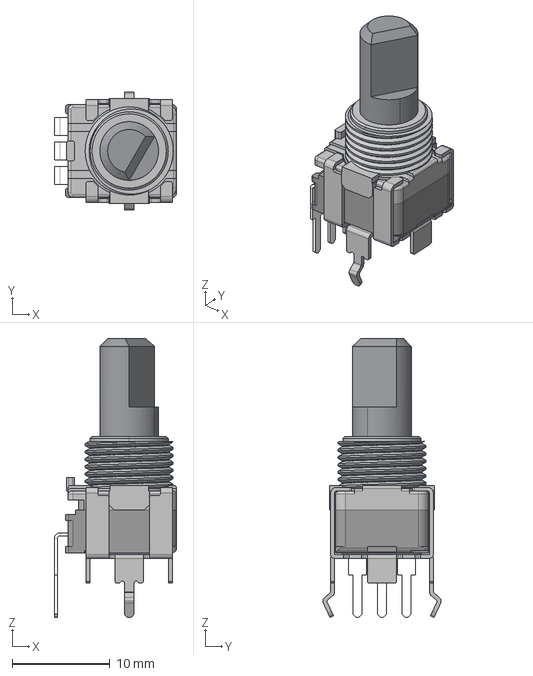
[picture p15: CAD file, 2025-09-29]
schematics/c3lingo_unit-assembly/kicad-libraries/c3lingo_unit-3dmodels/Potentiometer_Alps_RK09L1140_Single_Vertical.step
12.5 x 12.1 x 28.5 mm

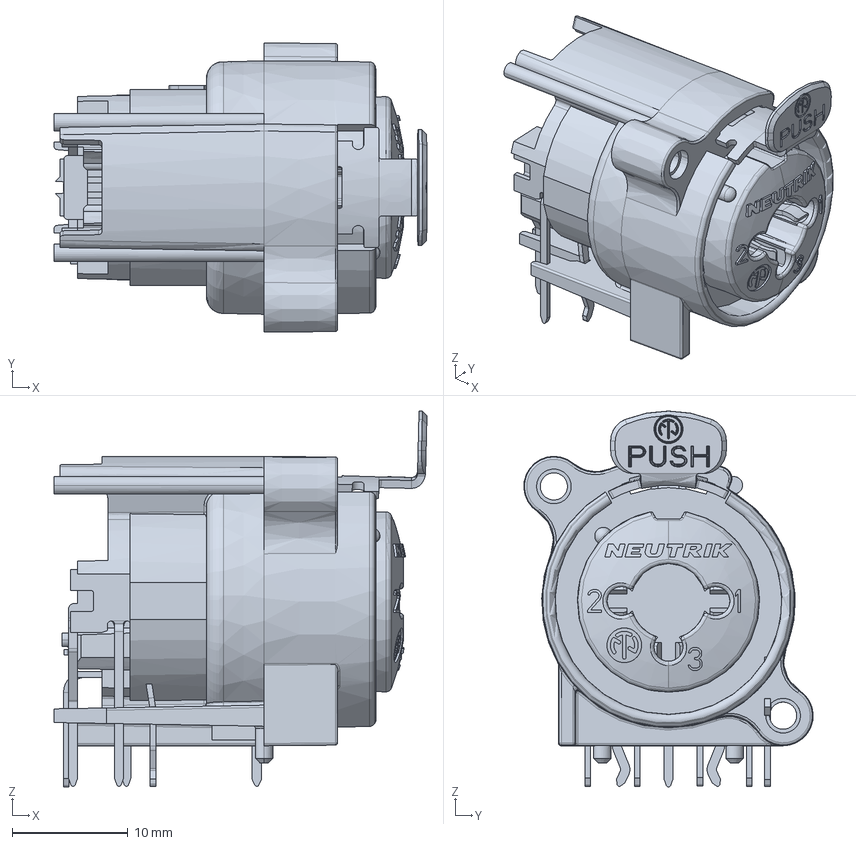
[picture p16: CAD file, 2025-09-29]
schematics/c3lingo_unit-assembly/kicad-libraries/c3lingo_unit-3dmodels/Jack_XLR-6.35mm_Neutrik_NCJ6FA-H_Horizontal.step
32.2 x 25.0 x 32.5 mm

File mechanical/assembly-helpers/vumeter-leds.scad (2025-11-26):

wall        = 2.0;
depth       = 11.5;

led_count   = 12;
led_width   = 5.5;
led_height  = 2.0;
led_space   = 0.5;

all_length = led_count*(led_height + led_space);

// main housing
difference() {
    cube([all_length + 2*wall,
      led_width + 2*wall,
      depth + wall]);
    
    translate([wall,wall,wall]) {
        // LED cutout
        cube([all_length,
              led_width,
              depth]);
        
        // resistor cutout
        cutout_depth = 1;
        cutout_diff = 0.5;
        translate([+cutout_diff/2,led_width,depth-cutout_depth]) {
            cube([all_length - cutout_diff, wall, cutout_depth]);
        }
        
        // capacitor cutout
        cutout_len = 3.5;
        cutout_offset = 0.8;
        translate([all_length,((led_width-cutout_len)/2+cutout_offset),depth-cutout_depth]) {
            cube([wall, cutout_len, cutout_depth]);
        }
    }
}

// ribs
rib_gap = 0.2;
rib_height = 2.5;
translate([wall+led_height+(rib_gap/2)+(led_space/2), wall, wall]){
    for (i = [0 : 1 : (led_count-2)]) {
        translate([i*(led_height+led_space), 0, 0]){
            cube([led_space - rib_gap, led_width, rib_height]);
        }
    }
}

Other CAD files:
mechanical/c3lingo-interpreter-unit_housing.FCStd
mechanical/c3lingo-interpreter-unit.FCStd
schematics/c3lingo_unit-assembly/kicad-libraries/c3lingo_unit-3dmodels/Potentiometer_Alps_RK09K_Single_Horizontal.step
schematics/c3lingo_unit-assembly/kicad-libraries/c3lingo_unit-3dmodels/TerminalBlock_Phoenix_SPTAF-1-4-3.5_1x04.step

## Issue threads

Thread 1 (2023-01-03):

ESD Protection/ Galvanic Isolation

jbeyerstedt, 2023-01-03:
I have not clue on ESD protection.
What is acutally needed and how can this be achieved?

GladOSkar, 2023-01-05:
I'd typically add bidirectional TVS diodes on all inputs of my digital circuits for this, not sure how well this translates to analog though

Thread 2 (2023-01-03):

Case Design

jbeyerstedt, 2023-01-03:
To cut cost and for more fun, a custom housing might be designed. There are no special requirements on the material used for now.

But the thickess of some walls is important because of the potentiometers, buttons and connectors sticking through it:
- top plate (main UI): 1.0 to 2.0 mm
- front side (headphone jacks): 1.0 to 2.0 mm
- back side (XLR line in and out, mains supply): less than 3 mm

Please see the BoM section of the readme for the model numbers of the used connectors, potentiometers and buttons and use their data sheets for the required hole pattern.

jbeyerstedt, 2023-01-15:
Possible options:
- https://www.takachi-enclosure.com/products/TS:
    * TS20-15: 35 mm H1 (25 mm panel), 70 mm H2 (60 mm panel), 200 mm W (180 mm panel), 150 mm D
    * TS29-21: 50 mm H1 (40 mm panel), 99 mm H2 (79 mm panel), 290 mm W (270 mm panel), 210 mm D
- https://www.takachi-enclosure.com/products/CF:
    * CF28-28GS: 50 mm H1 (27 mm panel), 99 mm H2 (72 mm panel), 280 mm W (261 mm panel), 280 mm D (238 mm panel)

jbeyerstedt, 2024-09-26:
New distance between mixer PCB and front plate is about 9 mm

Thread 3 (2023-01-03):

Improve/ Extend Power Supply

jbeyerstedt, 2023-01-03:
The electrical circuit needs some voltages to work:
- +15V and -15V for op-amps (< 100 mA) and LEDs (about 100 mA max.?)
- 48V for phantom power (if this feature is wanted/ needed)

The current prototype uses an off-the-shelf power supply module (MEAN WELL RT-65C; RT-50C should work, too), which works just fine without additional filtering.
But the 48 V phantom power is still an open question. We either need to get it from the +15 V or just do a completely different power supply design. Or the phantom power feature will just be removed all together.

jbeyerstedt, 2024-07-07:
To also add 48 V phantom power to the design, it either needs to be produced by a step-up DC/DC converter (which has a quite noisy output) or **another power supply**:

- Mean Well PT-45C (+15 V @1.6 A, -15V @0.3 A, +5 V @3 A)
- Mean Well PS-05-48 (+48 V @0.11 A)

Alternately some voltages can be produced by step-down DC/DC converters.
Their output power is depending on a pending decision, if the vu meter shall be powered by 15 or 5 V:

1. vu meter on 15 V: +15 V rail needs about 6.5 W power, 5 V line 1 W
2. vu meter on 5 V:  +15 V rail needs about 2 W power, 5 V line 3 W

**Two (less oversized) switching power supplies + DC/DC converter**
- Mean Well PD-2515 (+15 V @0.8 A, -15V @0.8 A)
- Mean Well PS-05-48 (+48 V @0.11 A)
- DC/DC from 15 to 5V
  - w/o vu meter (100mA): SPA01A-05, SPAN02A-05, SLC03A-05 or SCWN03A-05
  - with vu meter (400mA): SLC03A-05, SCWN03A-05 or SCWN06A-05

**48V wall adaptor + DC/DC converters**
- Mean Well NGE30E48-P1J (48 V, 0.63 A) or GST25A48-P1J (48 V, 0.52 A)
- vu meter on 15 V:
  - DC/DC to +-15V (600mA): DKMW15G-15
  - DC/DC to 5V (100mA): SPA01A-05, SPAN02A-05, SLC03A-05 or SCWN03A-05
- vu meter on 5 V:
  - DC/DC to +-15V (100mA): DPBW03G-15 (ext. EMC req.), DLC03C-15, DCWN03C-15 or DCWN06C-15
  - DC/DC to 5V (400mA): SLC03A-05, SCWN03A-05 or SCWN06A-05

jbeyerstedt, 2024-10-26:
Options when leaving out 48V (or generating it from +15V somehow):
- Mean Well RT-50C (5V, 4A; +15V, 1.5A; -15V, 0.5A), enclosed type: ~20€ incl. VAT
- 48V wall adaptor + DC/DC (DCWN03C-15) as mentioned above: ~29€ incl. VAT

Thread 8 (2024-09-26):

Errata/ Notes on Revision 0.3.3

jbeyerstedt, 2024-09-26:
Loose collection of things which I noticed when using prototype 2 (v0.3.3) for the first time:

Positive:
- Microphone and headphones noise floor seems to be quite a lot lower than at prototype 1
- vu meter low-pass filtering is not really noticeable (I like the quite snappy response)
- It still works

To improve:
- vu meter does not reach the top LED before the microphone clips at the headphones and line output
  - TODO: Increase amplification or change reference voltages
- low-pass filter of vu meter amplifier/ rectifier has a DC offset. Lowest LED is always lit, bottom 5 LEDs when microphone is "on"
- headphones have a bit too harsh high-end for my taste
- muting delay is too long (takes about 1 second to fade down, should be more like 100 ms max)
- microphone gain might be a bit too high (1/8 turn (should be about 10 dB) is fine for SM58 and HMD660)

EDIT: More to improve:
- Replace line input trim with a 10k resistor (empirical value for 0 dBu) or just make the op-amp stage unity gain. Question: Is the op-amp stage needed at all then?
- Add some low-pass filtering on the microphone input
- Maybe: Reduce line out by 6 dB (it clips my audio interface quite easily)

jbeyerstedt, 2024-09-26:
Also: Replace line input trim with a 10k resistor (empirical value for 0 dBu) or just make the op-amp stage unity gain

jbeyerstedt, 2024-11-14:
Required rework:

- Channel Mixer:
  - Replace C314 with 100nF (less muting delay)
  - Replace C301 with 680pF (11 kHz low-pass on headphone)
  - Replace R309 with 8.2K, replace R232 with 220R, replace R335 with 18K (adjust vu meter scale to -27 to +6 dBu)
  - optional: Replace R303 with 1K (reduce microphone gain range to 34 dB instead of 45 dB)
- Channel I/O:
  - Add 220pF in parallel to R602 (10kHz low-pass on microphone to reduce high-frequency noise)

jbeyerstedt, 2024-11-16:
Remaining points (which require layout changes or more changed components) are moved to #9

Closed 2024-11-28.

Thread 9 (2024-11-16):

Fixes/ Features for next PCB revision

jbeyerstedt, 2024-11-16:
After using the second PCB revision (v0.3.3) and applying some rework, some more fixes are left for a new PCB revision:

- [ ] General: Use IDC connectors for board-to-board connections (easier to build the cables)
- [ ] Channel Mixer: Use new resistors in the reference value ladder of the microphone level meter (aka VU meter)
- [ ] Channel Mixer: Reduce adjustable microphone gain range to 34dB instead of 45dB (R303 = 1K)
- [ ] Line I/O: Remove adjustable gain on line input, maybe even completely remove the second OpAmp
- [ ] Line I/O: Reduce summing gain to -6 dB (so output is 0 dBu nominally)
- [ ] Channel Mixer: Replace SMD LEDs with 2x5 mm rectangular THD LEDs?

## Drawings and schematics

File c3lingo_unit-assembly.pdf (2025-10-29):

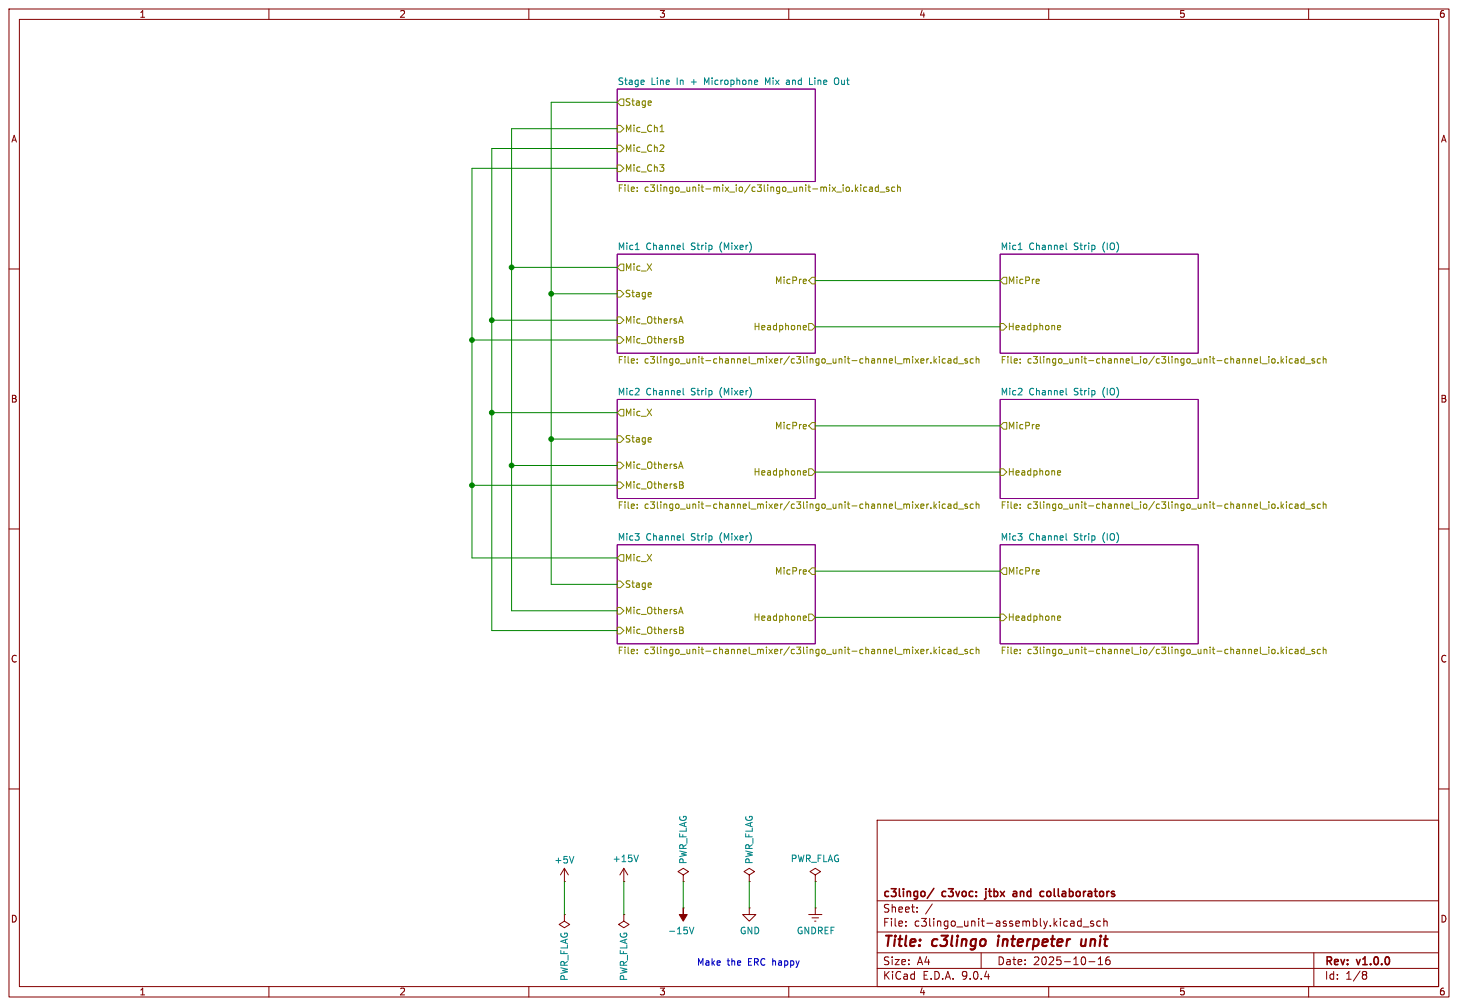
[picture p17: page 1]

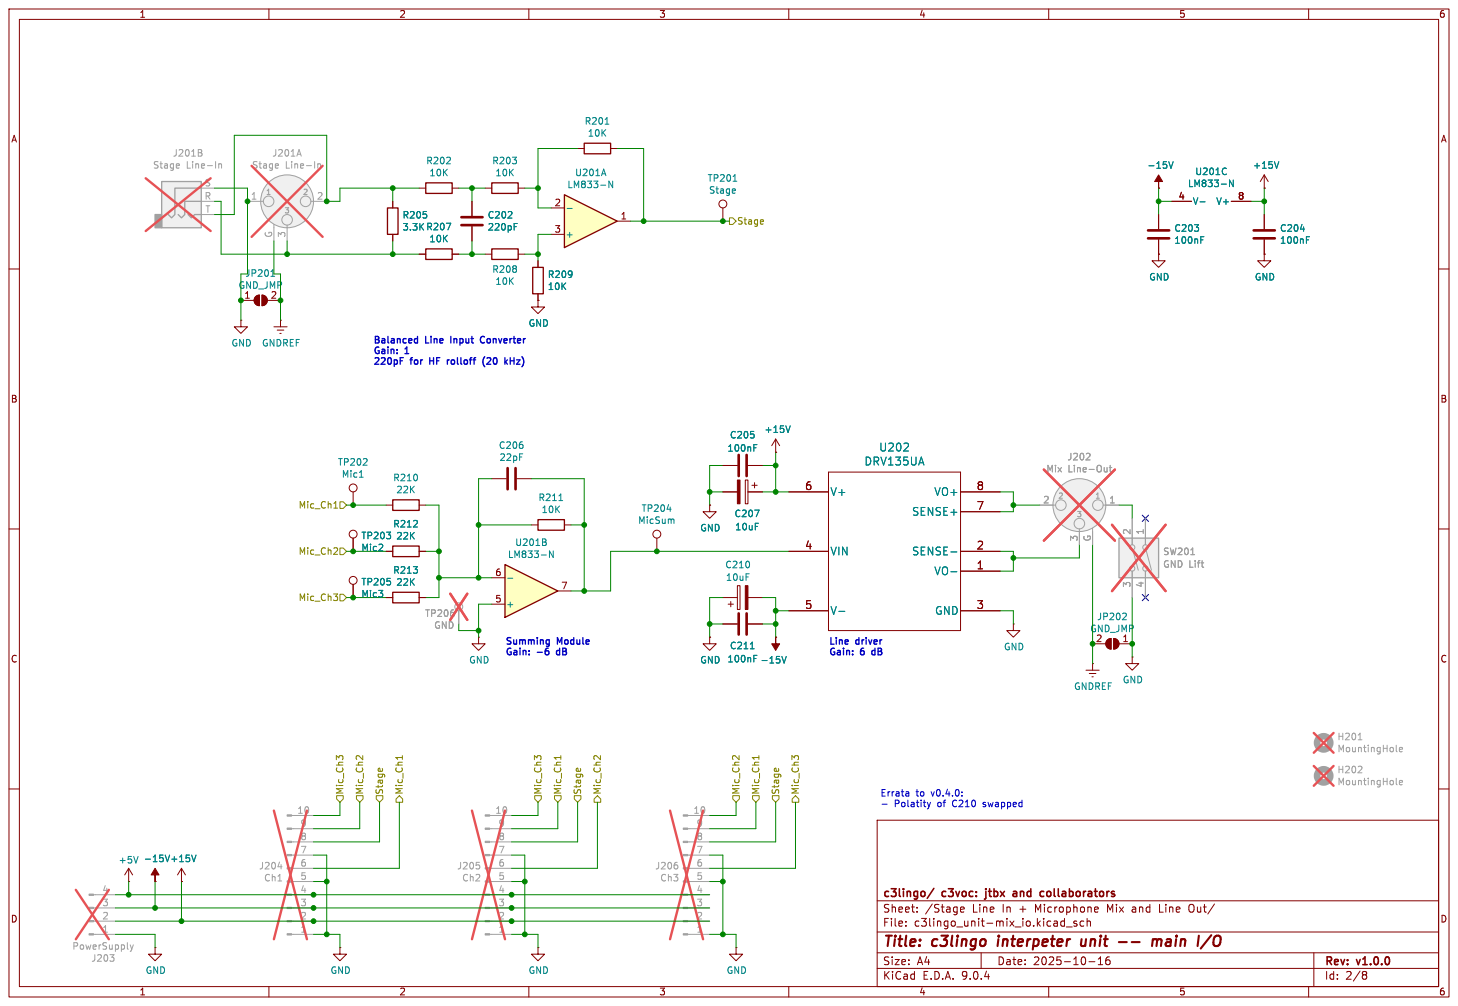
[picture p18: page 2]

Balanced Line Input Converter Gain: 1

220pF for HF rolloff (20 kHz) TP203 Mic2 TP205 Mic3 R213

4 SW201 GND Lift -15V GND GND

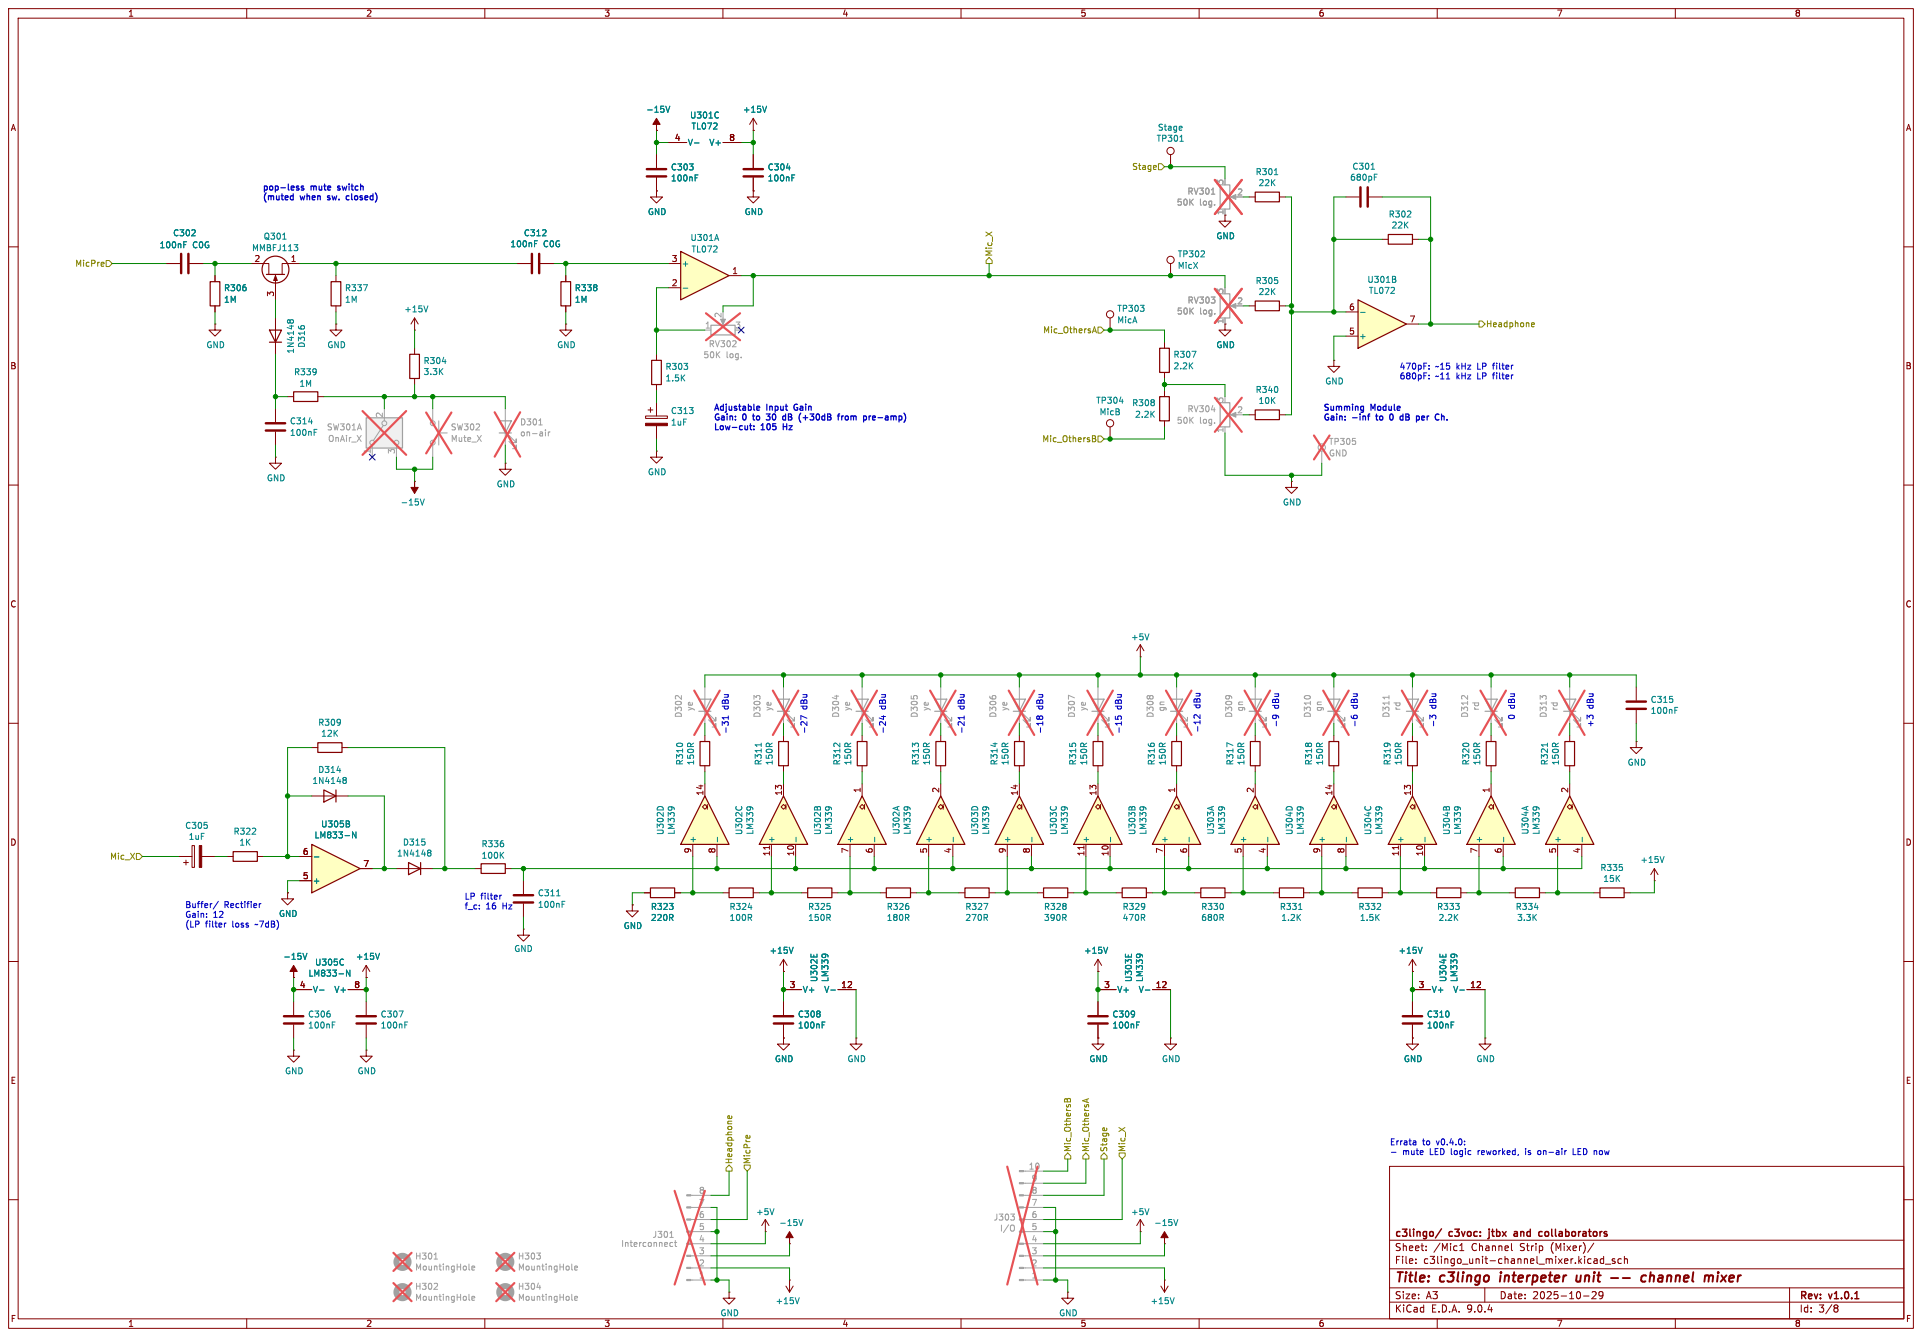
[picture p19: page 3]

(muted when sw. closed)

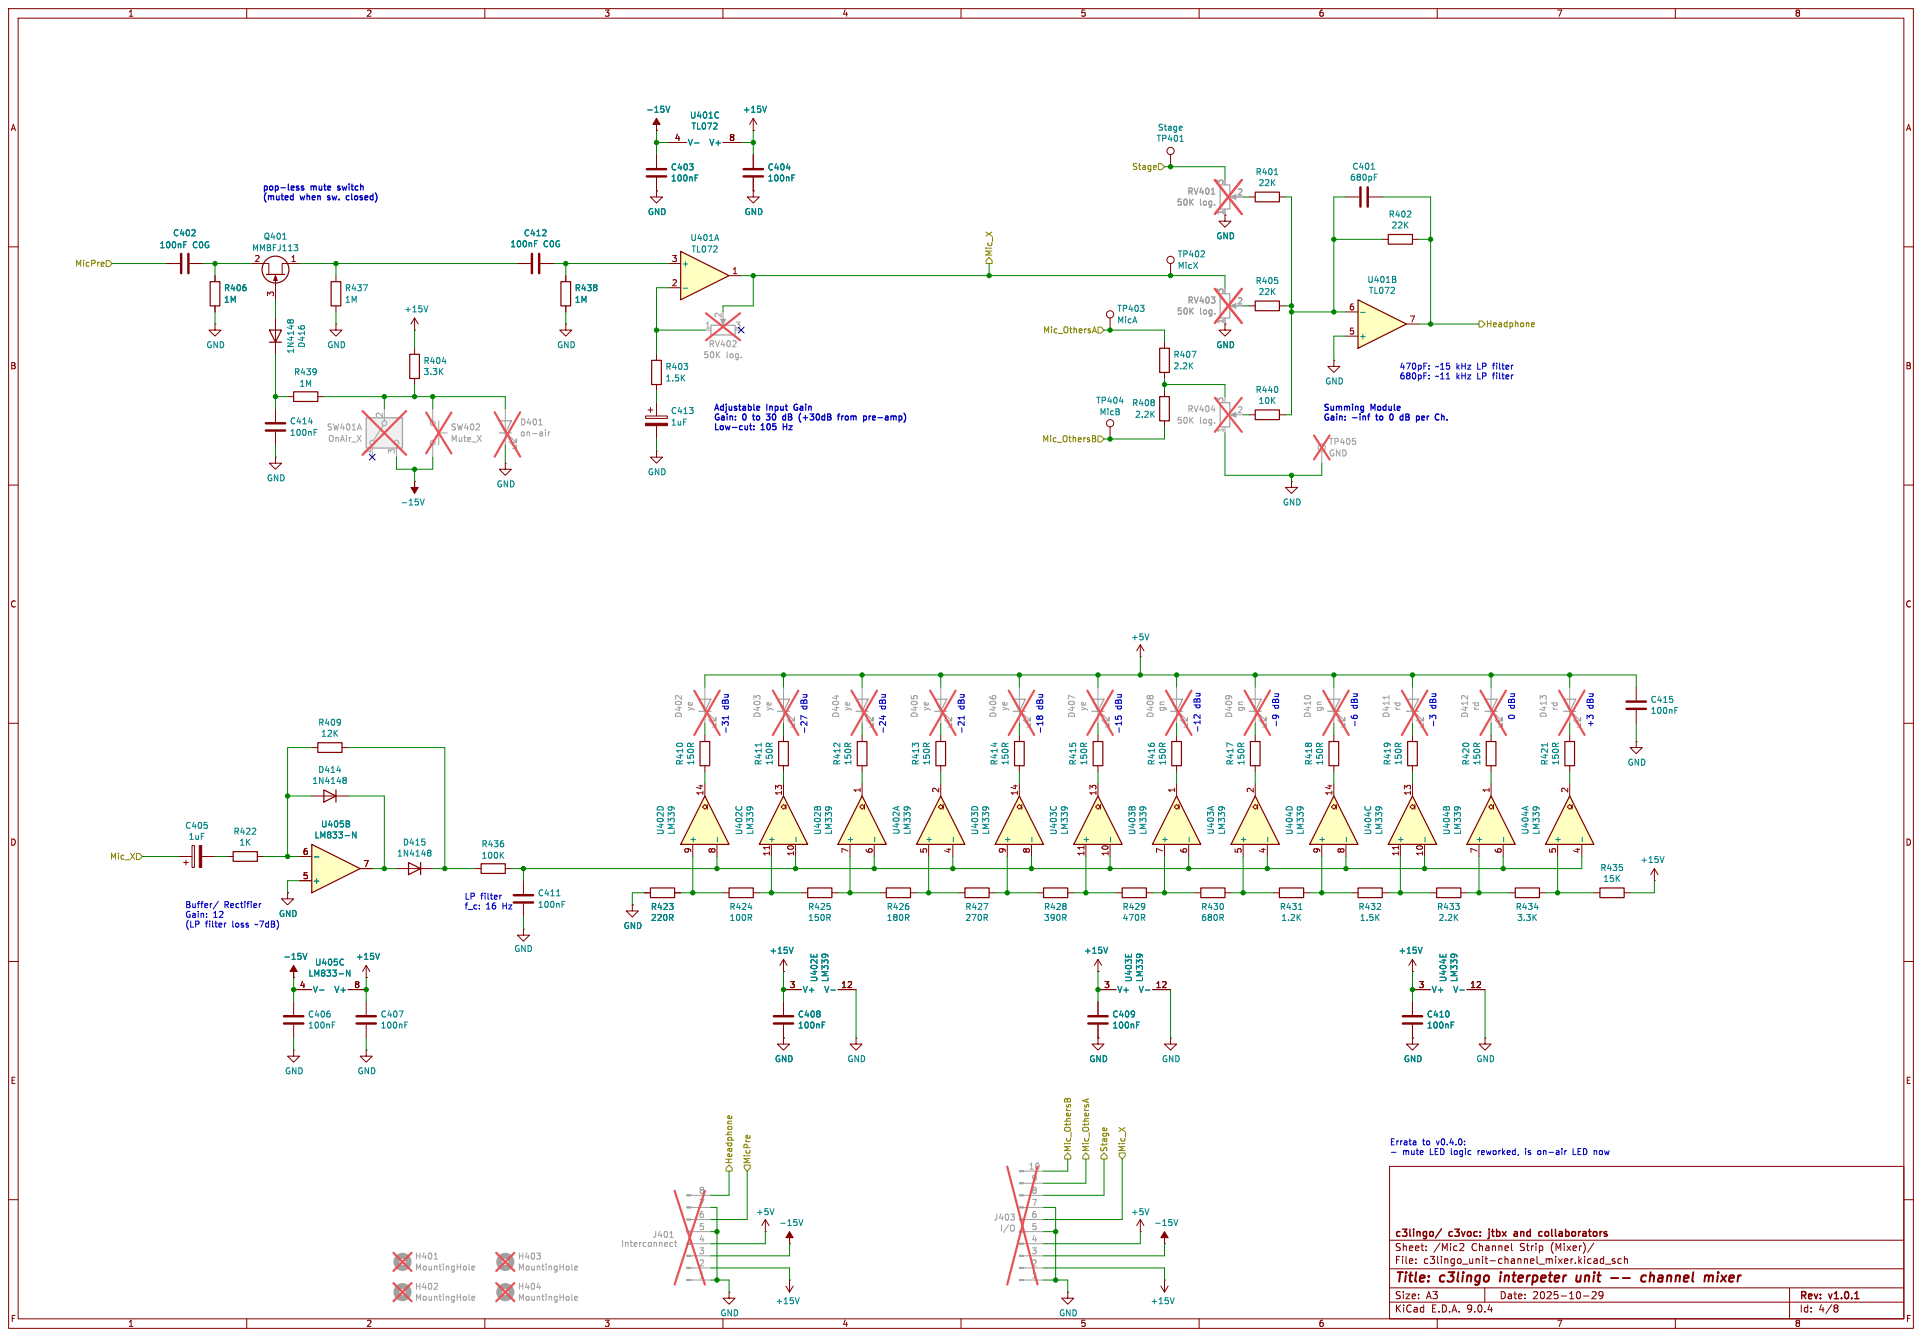
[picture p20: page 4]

(muted when sw. closed)

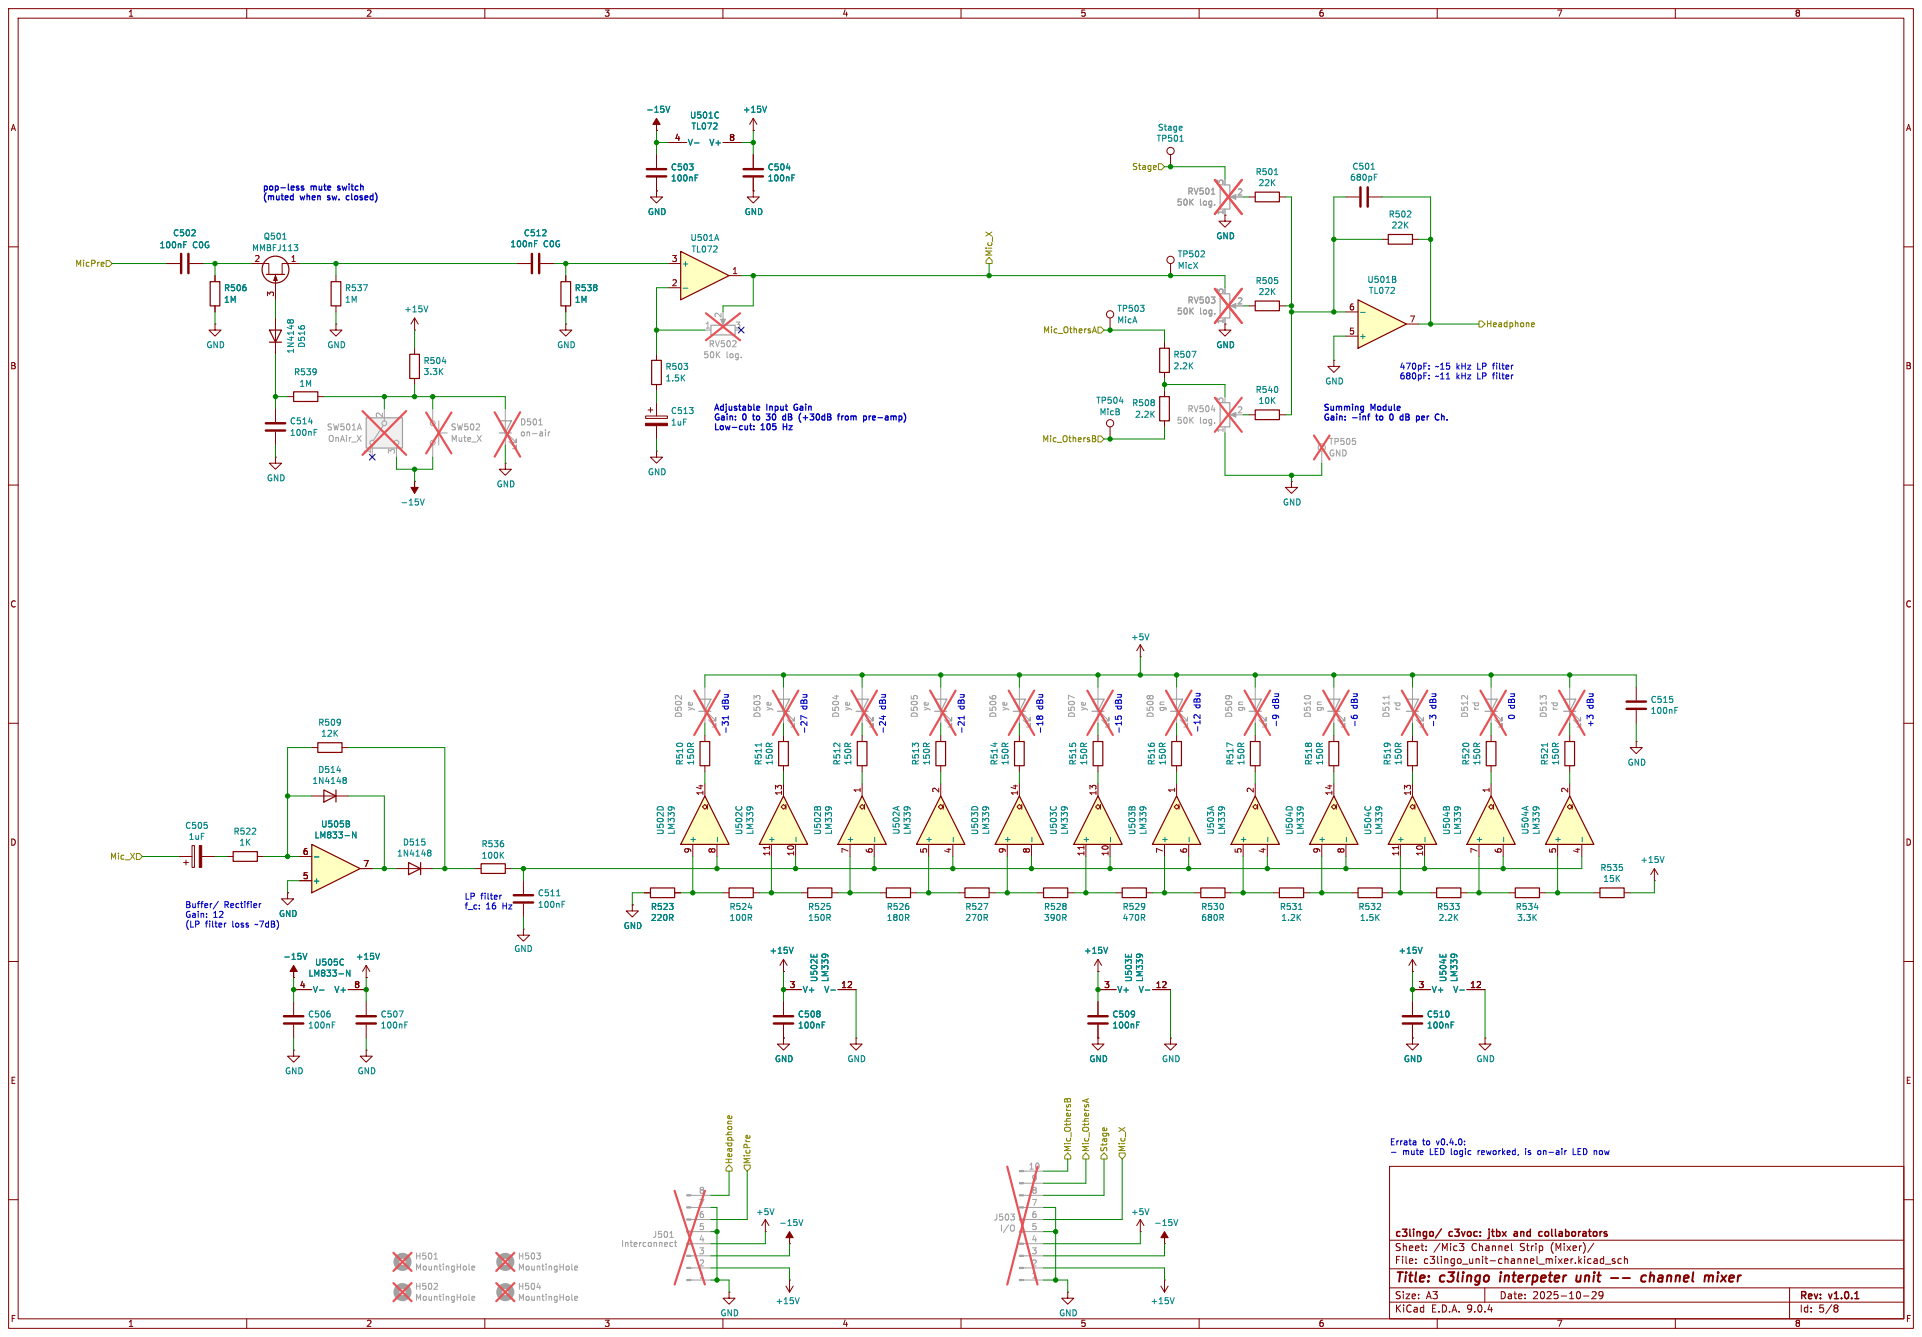
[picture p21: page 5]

(muted when sw. closed)

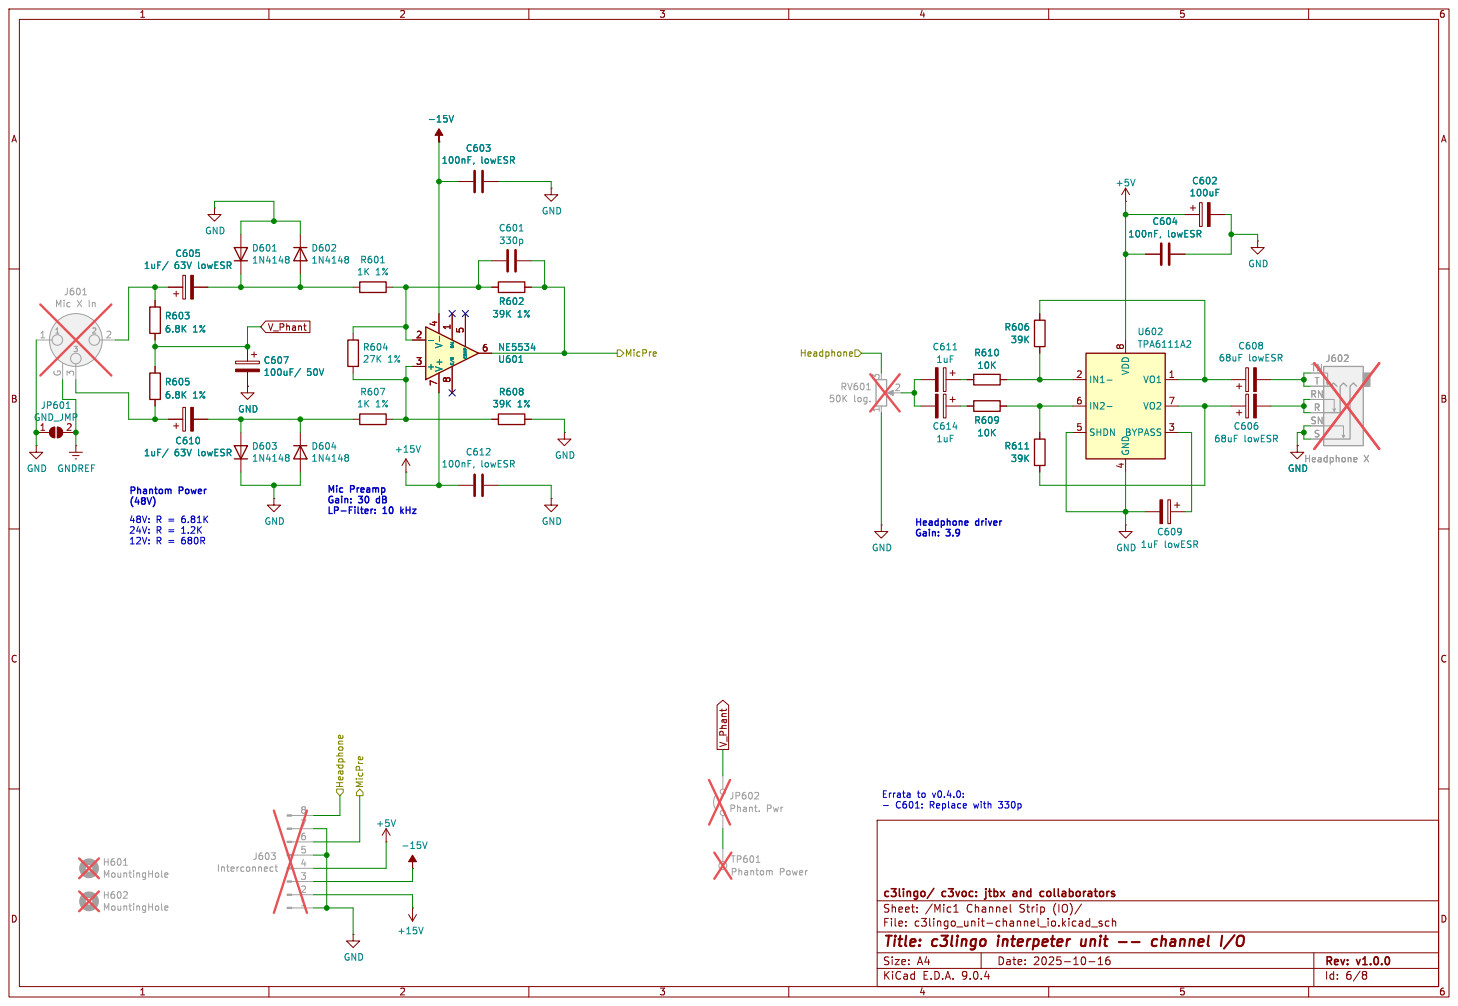
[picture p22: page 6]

TP601 Phantom Power JP602 Phant. Pwr C610
1uF/ 63V lowESR

Headphone driver Gain: 3.9 Mic Preamp Gain: 30 dB

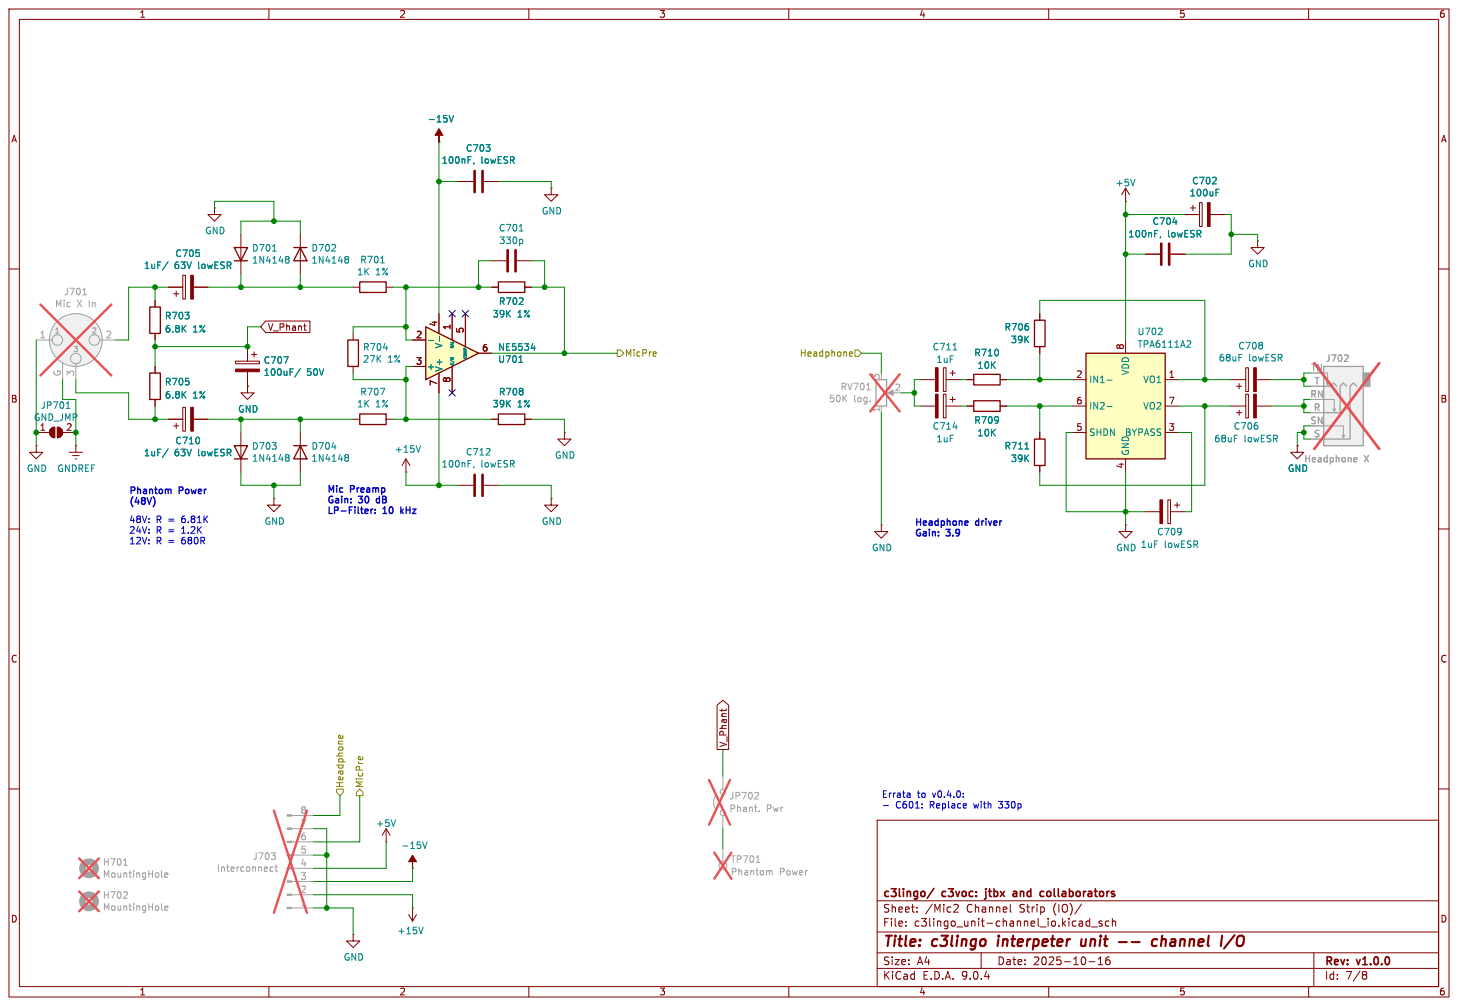
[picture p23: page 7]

TP701 Phantom Power JP702 Phant. Pwr D703

Headphone driver Gain: 3.9 Mic Preamp Gain: 30 dB

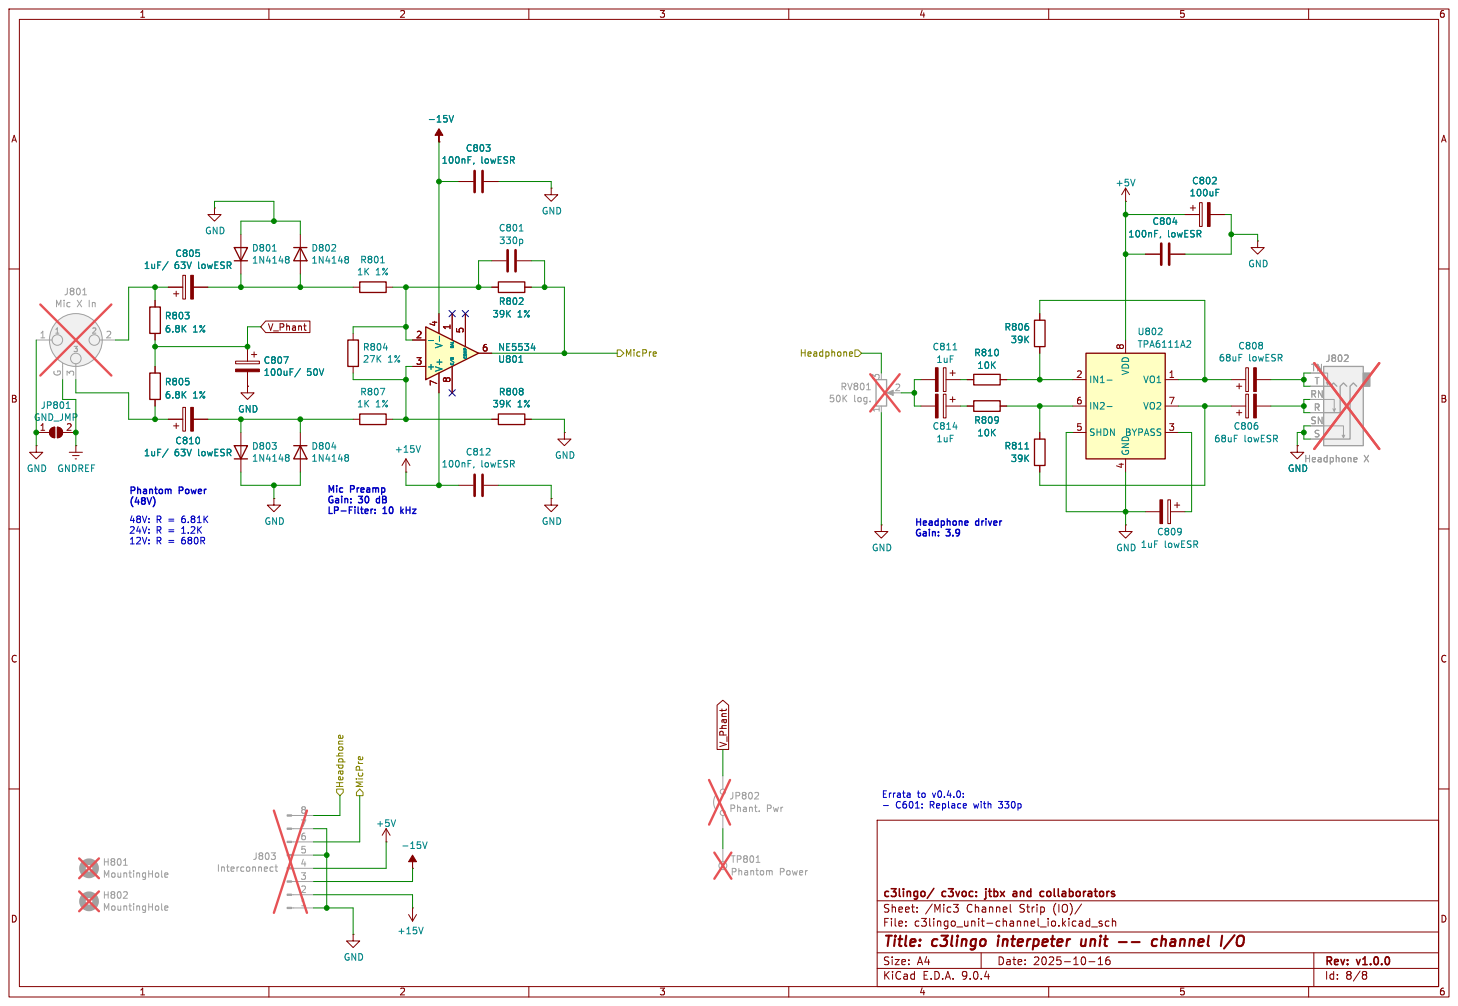
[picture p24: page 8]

TP801 Phantom Power JP802 Phant. Pwr C810
1uF/ 63V lowESR

Headphone driver Gain: 3.9 Mic Preamp Gain: 30 dB

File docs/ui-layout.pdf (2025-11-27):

# Mic Gain

# Channel 1

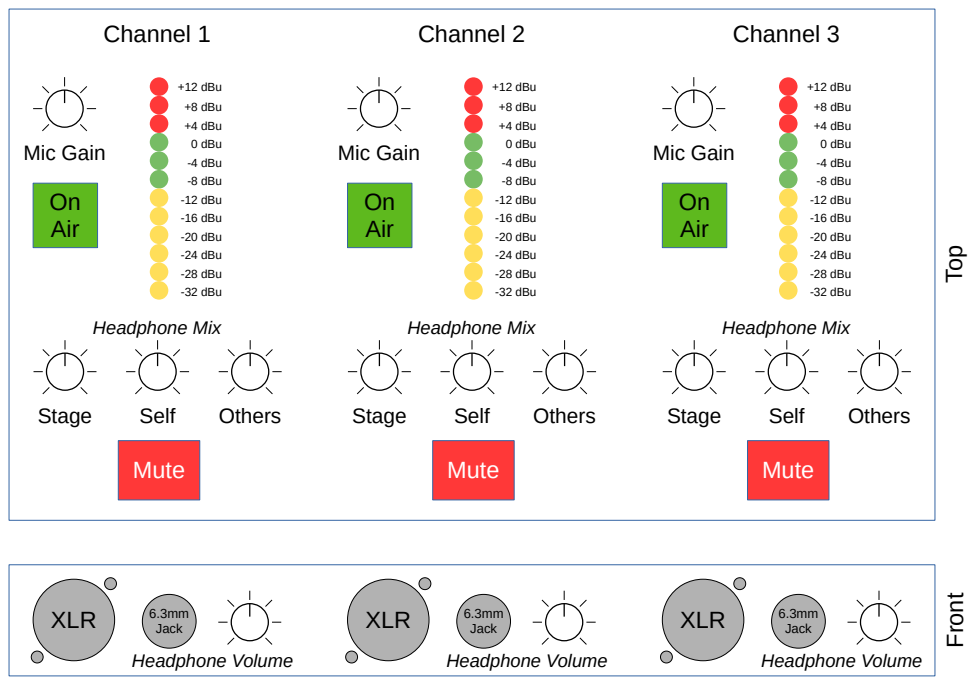
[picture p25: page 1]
Self; +12 dBu; +8 dBu +4 dBu 0 dBu -4 dBu -8 dBu -12 dBu -16 dBu -20 dBu -24 dBu -28 dBu -32 dBu; Stage; Others; 6.3mm XLR; Jack; Fro; Mute; On Air; Headphone Mix; Headphone Volume; Mic Gain; Channel 3; Channel 2

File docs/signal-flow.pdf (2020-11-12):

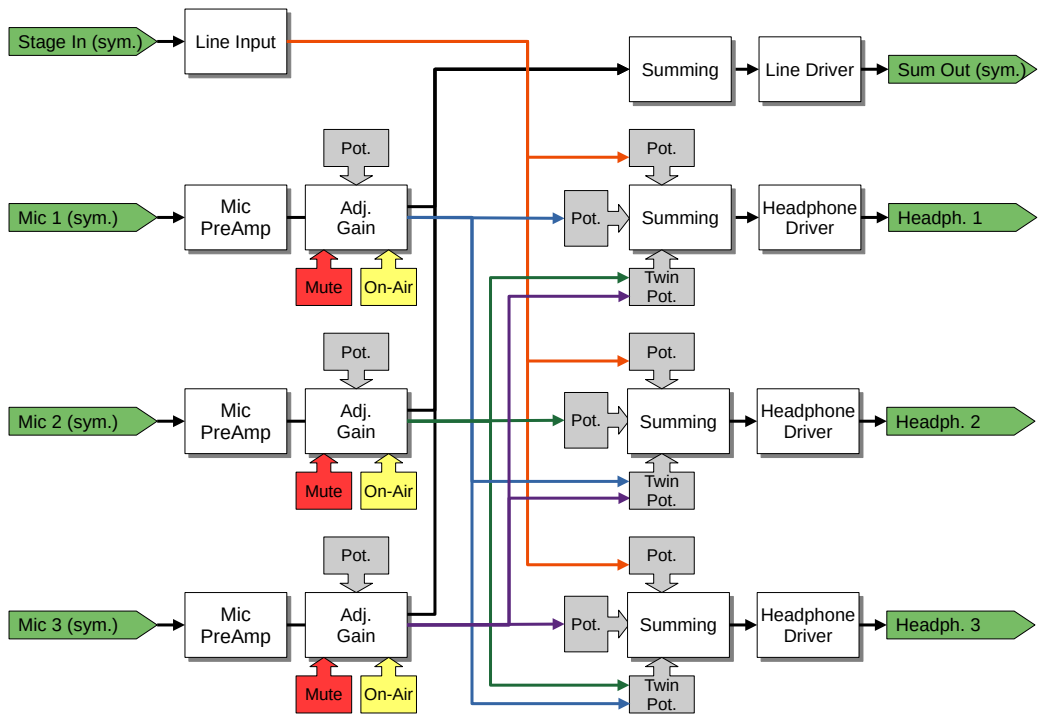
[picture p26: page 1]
Pot.; Mic PreAmp; Mic Mic 1 (sym.); Headph. 1; Adj. Gain; Adj.; Line Input; Line Driver; Headphone Driver; Mic Mic 2 (sym.); Gain; Mic Mic 3 (sym.); Summing; Headphone; Headph. 2; Driver; Headph. 3; Twin Pot.

Stage In (sym.)

Sum Out (sym.)

Mute On-Air

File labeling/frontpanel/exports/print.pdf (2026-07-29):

### c3lingo Interpreter Desk

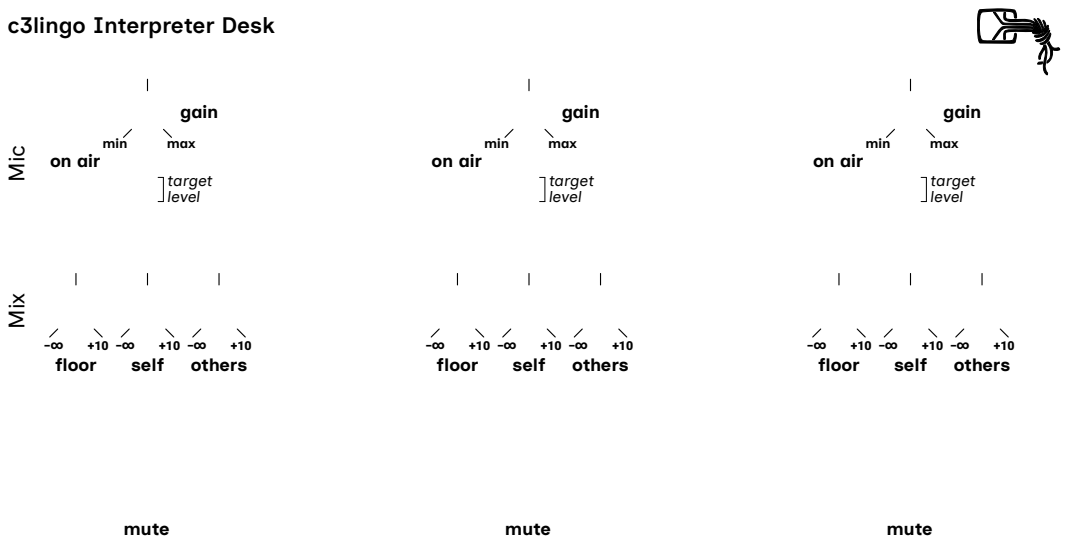
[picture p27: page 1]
Mic Mix; on air; gain; min; max; mute; target level; floor; self; others

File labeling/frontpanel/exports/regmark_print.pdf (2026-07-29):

Mic Mix

### c3lingo Interpreter Desk

on air

gain

min | max

mute

target
level

floor

−∞ +10
self

−∞ +10
others

−∞ +10

on air

gain

min | max

mute

target
level

floor

−∞ +10
self

−∞ +10
others

−∞ +10

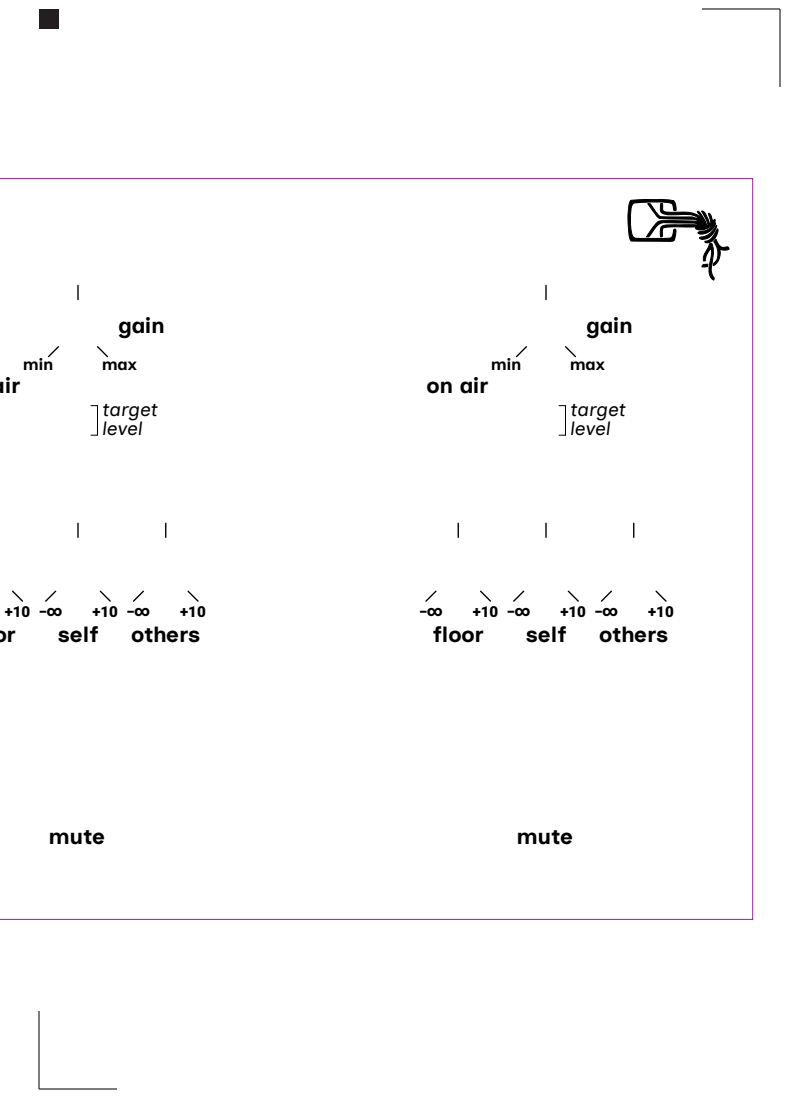
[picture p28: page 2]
on air; gain; min; max; mute; target level; floor; self; others





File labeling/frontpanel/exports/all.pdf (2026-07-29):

### c3lingo Interpreter Desk

Mic Mix; on air; gain; min; max; mute; target level; floor; self; others

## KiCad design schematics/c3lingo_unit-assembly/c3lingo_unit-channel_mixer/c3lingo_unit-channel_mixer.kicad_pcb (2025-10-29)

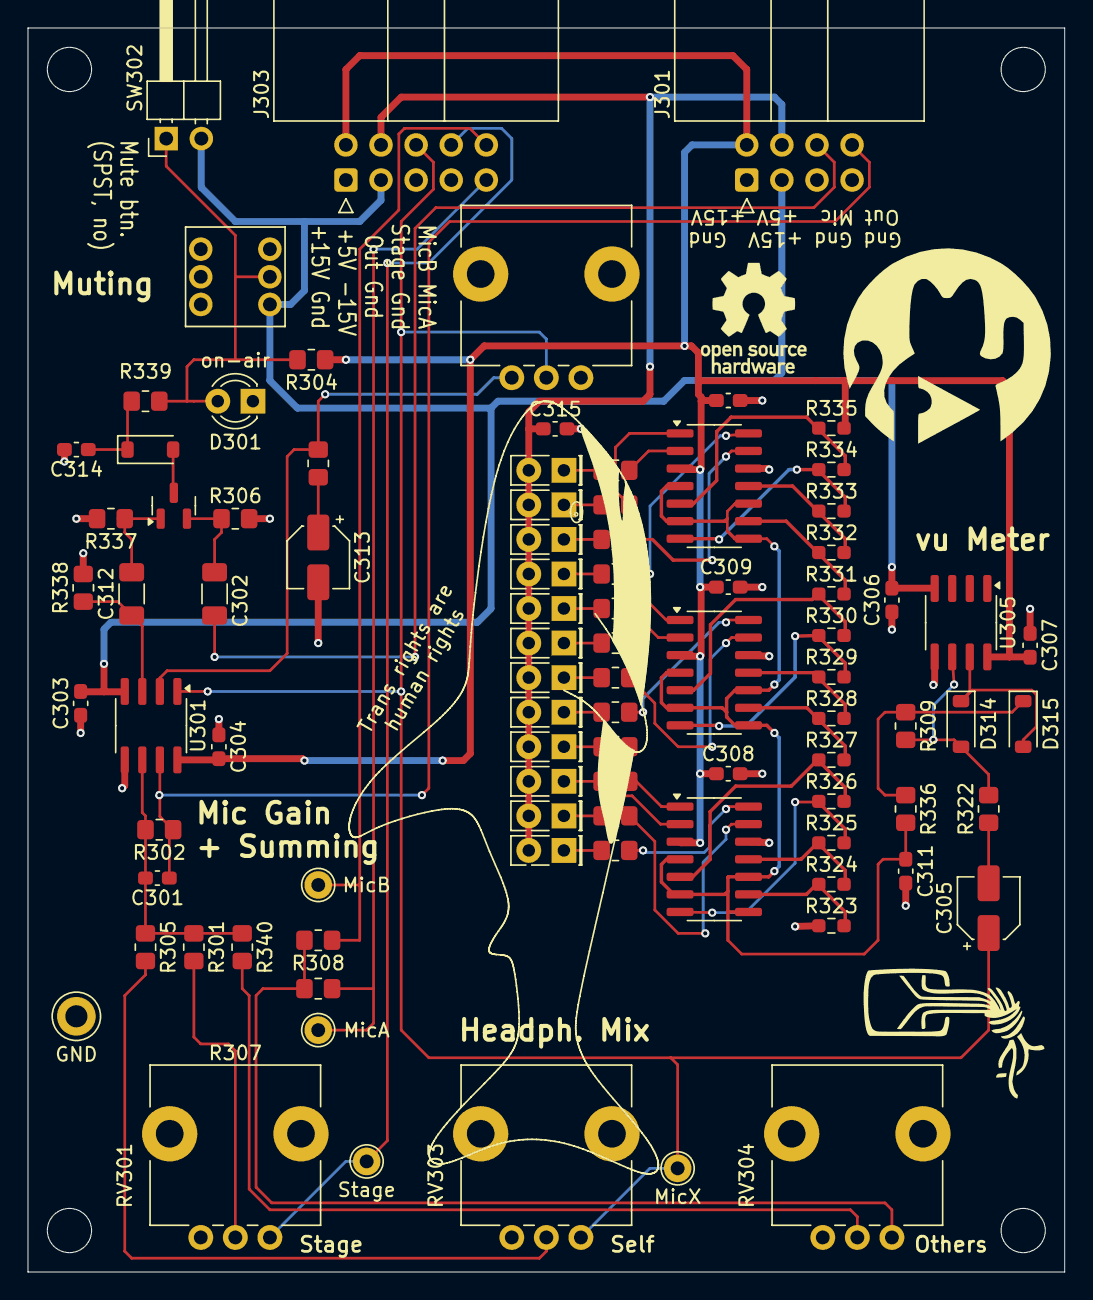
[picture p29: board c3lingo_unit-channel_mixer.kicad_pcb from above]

Board: 2 copper layers, 75.0 x 90.0 mm, 94 parts (0 on the bottom side), 64 nets.

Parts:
C301: 680pF; C_0603_1608Metric_Pad1.08x0.95mm_HandSolder
C302, C312: 100nF C0G; C_1206_3216Metric_Pad1.33x1.80mm_HandSolder
C303, C304, C306, C307, C308, C309, C310, C311, C314, C315: 100nF; C_0603_1608Metric_Pad1.08x0.95mm_HandSolder
C305, C313: 1uF; CP_Elec_4x5.8
D301: on-air; LED_D3.0mm
D302, D303, D304, D305, D306, D307: ye; LED_Rectangular_W5.0mm_H2.0mm
D308, D309, D310: gn; LED_Rectangular_W5.0mm_H2.0mm
D311, D312, D313: rd; LED_Rectangular_W5.0mm_H2.0mm
D314, D315, D316: 1N4148; D_SOD-123
H301, H302, H303, H304: MountingHole; MountingHole_3.2mm_M3
J301: Interconnect; IDC-Header_2x04_P2.54mm_Horizontal
J303: I/O; IDC-Header_2x05_P2.54mm_Horizontal
Q301: MMBFJ113; SOT-23
R301, R302, R305: 22K; R_0805_2012Metric_Pad1.20x1.40mm_HandSolder
R303: 1.5K; R_0805_2012Metric_Pad1.20x1.40mm_HandSolder
R304: 3.3K; R_0805_2012Metric_Pad1.20x1.40mm_HandSolder
R306, R337, R338, R339: 1M; R_0805_2012Metric_Pad1.20x1.40mm_HandSolder
R307, R308: 2.2K; R_0805_2012Metric_Pad1.20x1.40mm_HandSolder
R309: 12K; R_0805_2012Metric_Pad1.20x1.40mm_HandSolder
R310, R311, R312, R313, R314, R315, R316, R317, R318, R319, R320, R321: 150R; R_0805_2012Metric_Pad1.20x1.40mm_HandSolder
R322: 1K; R_0805_2012Metric_Pad1.20x1.40mm_HandSolder
R323: 220R; R_0603_1608Metric_Pad0.98x0.95mm_HandSolder
R324: 100R; R_0603_1608Metric_Pad0.98x0.95mm_HandSolder
R325: 150R; R_0603_1608Metric_Pad0.98x0.95mm_HandSolder
R326: 180R; R_0603_1608Metric_Pad0.98x0.95mm_HandSolder
R327: 270R; R_0603_1608Metric_Pad0.98x0.95mm_HandSolder
R328: 390R; R_0603_1608Metric_Pad0.98x0.95mm_HandSolder
R329: 470R; R_0603_1608Metric_Pad0.98x0.95mm_HandSolder
R330: 680R; R_0603_1608Metric_Pad0.98x0.95mm_HandSolder
R331: 1.2K; R_0603_1608Metric_Pad0.98x0.95mm_HandSolder
R332: 1.5K; R_0603_1608Metric_Pad0.98x0.95mm_HandSolder
R333: 2.2K; R_0603_1608Metric_Pad0.98x0.95mm_HandSolder
R334: 3.3K; R_0603_1608Metric_Pad0.98x0.95mm_HandSolder
R335: 15K; R_0603_1608Metric_Pad0.98x0.95mm_HandSolder
R336: 100K; R_0805_2012Metric_Pad1.20x1.40mm_HandSolder
R340: 10K; R_0805_2012Metric_Pad1.20x1.40mm_HandSolder
RV301, RV302, RV303, RV304: 50K log.; Potentiometer_CUI_PTN09X_Single_Vertical
SW301: OnAir_X; SW_APEM_MHPS2273_DPDT
SW302: Mute_X; PinHeader_1x02_P2.54mm_Horizontal
TP301: Stage; TestPoint_THTPad_D2.0mm_Drill1.0mm
TP302: MicX; TestPoint_THTPad_D2.0mm_Drill1.0mm
TP303: MicA; TestPoint_THTPad_D2.0mm_Drill1.0mm
TP304: MicB; TestPoint_THTPad_D2.0mm_Drill1.0mm
TP305: GND; TestPoint_Keystone_5005-5009_Compact
U301: TL072; SOIC-8_3.9x4.9mm_P1.27mm
U302, U303, U304: LM339; SOIC-14_3.9x8.7mm_P1.27mm
U305: LM833-N; SOIC-8_3.9x4.9mm_P1.27mm

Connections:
+5V: C315.1, D302.2 (A), D303.2 (A), D304.2 (A), D305.2 (A), D306.2 (A), D307.2 (A), D308.2 (A), D309.2 (A), D310.2 (A), D311.2 (A), D312.2 (A), D313.2 (A), J301.4, J303.4
+15V: C304.2, C307.2, C308.1, C309.1, C310.1, J301.2, J303.2, R304.1, R335.2, U301.8 (V+), U302.3 (V+), U303.3 (V+), U304.3 (V+), U305.8 (V+)
-15V: C303.2, C306.2, J301.3, J303.3, SW301.3 (C), SW302.2, U301.4 (V-), U305.4 (V-)
/Headphone: C301.1, J301.8, R302.1, U301.7
/MicPre: C302.2, J301.6
/Mic_OthersA: J303.9, R307.1, TP303.1
/Mic_OthersB: J303.10, R308.1, TP304.1
/Mic_X: C305.1, J303.6, RV302.2, RV303.3, TP302.1, U301.1
/Stage: J303.8, RV301.3, TP301.1
GND: C303.1, C304.1, C306.1, C307.1, C308.2, C309.2, C310.2, C311.2, C313.2, C314.2, C315.2, D301.1 (K), J301.1, J301.5, J301.7, J303.1, J303.5, J303.7, R306.2, R323.1, R337.2, R338.2, RV301.1, RV303.1, RV304.1, TP305.1, U301.5 (+), U302.12 (V-), U303.12 (V-), U304.12 (V-), U305.5 (+)
unnamed: C305.2, R322.1
unnamed: C313.1, R303.2
unnamed: D301.2 (A), R304.2, R339.2, SW301.2 (B), SW302.1
unnamed: D302.1 (K), R310.1
unnamed: D303.1 (K), R311.1
unnamed: D304.1 (K), R312.1
unnamed: D305.1 (K), R313.1
unnamed: D306.1 (K), R314.1
unnamed: D307.1 (K), R315.1
unnamed: D308.1 (K), R316.1
unnamed: D309.1 (K), R317.1
unnamed: D310.1 (K), R318.1
unnamed: D311.1 (K), R319.1
unnamed: D312.1 (K), R320.1
unnamed: D313.1 (K), R321.1
unnamed: D314.2 (A), R309.2, R322.2, U305.6 (-)
unnamed: D314.1 (K), D315.2 (A), U305.7
unnamed: D315.1 (K), R309.1, R336.1
unnamed: D316.2 (A), Q301.3 (G)
unnamed: C314.1, D316.1 (K), R339.1
unnamed: C312.2, Q301.1 (D), R337.1
unnamed: C302.1, Q301.2 (S), R306.1
unnamed: R301.2, RV301.2
unnamed: R305.2, RV303.2
unnamed: R307.2, R308.2, RV304.3
unnamed: R310.2, U302.14
unnamed: R311.2, U302.13
unnamed: R312.2, U302.1
unnamed: R313.2, U302.2
unnamed: R314.2, U303.14
unnamed: R315.2, U303.13
unnamed: R316.2, U303.1
unnamed: R317.2, U303.2
unnamed: R318.2, U304.14
unnamed: R319.2, U304.13
unnamed: R320.2, U304.1
unnamed: R321.2, U304.2
unnamed: R340.2, RV304.2
unnamed: C312.1, R338.1, U301.3 (+)
unnamed: R303.1, RV302.1, U301.2 (-)
unnamed: C301.2, R301.1, R302.2, R305.1, R340.1, U301.6 (-)
unnamed: R326.2, R327.1, U302.5 (+)
unnamed: C311.1, R336.2, U302.4 (-), U302.6 (-), U302.8 (-), U302.10 (-), U303.4 (-), U303.6 (-), U303.8 (-), U303.10 (-), U304.4 (-), U304.6 (-), U304.8 (-), U304.10 (-)
unnamed: R325.2, R326.1, U302.7 (+)
unnamed: R324.2, R325.1, U302.11 (+)
unnamed: R323.2, R324.1, U302.9 (+)
unnamed: R330.2, R331.1, U303.5 (+)
unnamed: R329.2, R330.1, U303.7 (+)
unnamed: R328.2, R329.1, U303.11 (+)
unnamed: R327.2, R328.1, U303.9 (+)
unnamed: R334.2, R335.1, U304.5 (+)
unnamed: R333.2, R334.1, U304.7 (+)
unnamed: R332.2, R333.1, U304.11 (+)
unnamed: R331.2, R332.1, U304.9 (+)

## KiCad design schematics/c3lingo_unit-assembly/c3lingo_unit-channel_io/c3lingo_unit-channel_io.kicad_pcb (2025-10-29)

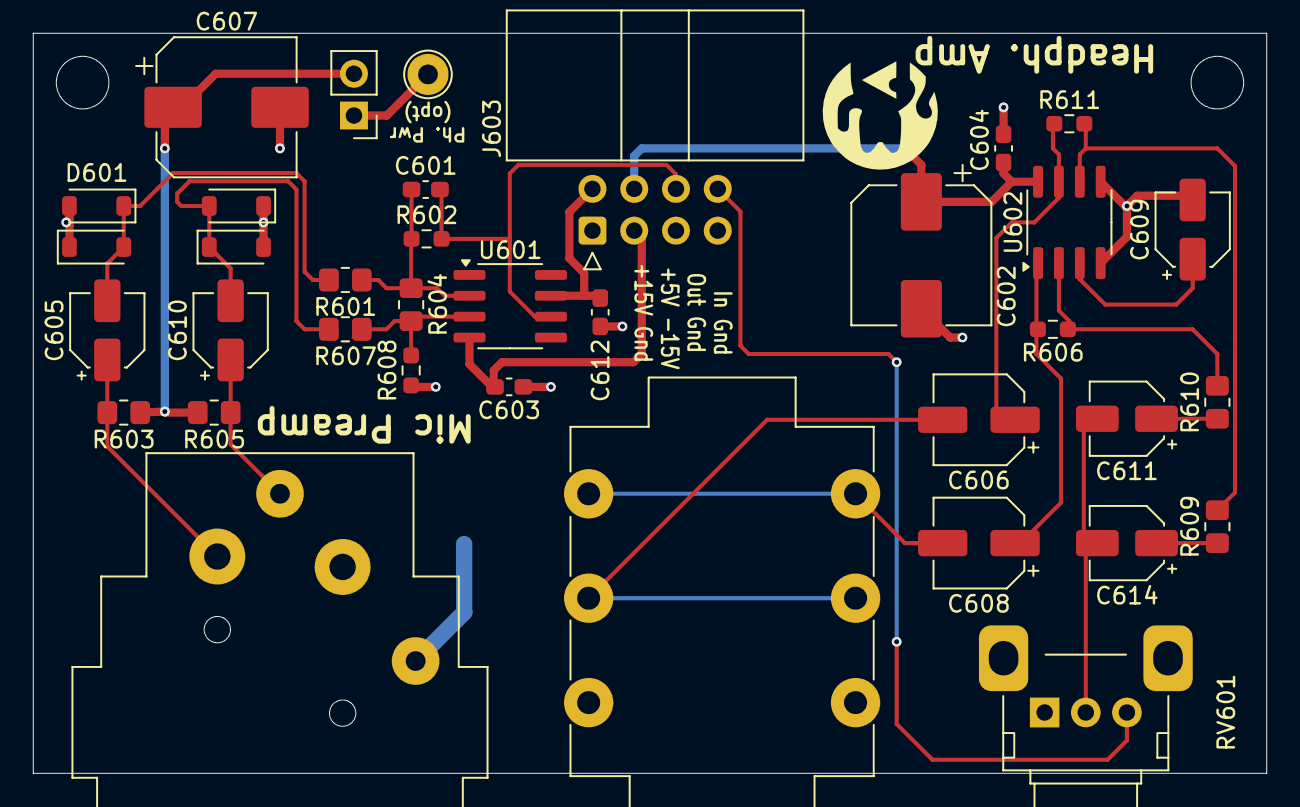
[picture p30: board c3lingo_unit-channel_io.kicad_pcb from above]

Board: 2 copper layers, 75.0 x 45.0 mm, 39 parts (1 on the bottom side), 25 nets.

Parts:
C601: 330p; C_0603_1608Metric_Pad1.08x0.95mm_HandSolder
C602: 100uF; CP_Elec_8x10
C603, C604, C612: 100nF, lowESR; C_0603_1608Metric_Pad1.08x0.95mm_HandSolder
C605, C610: 1uF/ 63V lowESR; CP_Elec_4x5.8
C606, C608: 68uF lowESR; CP_Elec_5x5.8
C607: 100uF/ 50V; CP_Elec_8x10
C609: 1uF lowESR; CP_Elec_4x5.8
C611, C614: 1uF; CP_Elec_4x5.8
D601, D602, D603, D604: 1N4148; D_SOD-123
H601, H602: MountingHole; MountingHole_3.2mm_M3
J601: Mic X In; Jack_XLR_Neutrik_NC3FAAH2_Horizontal
J602: Headphone X; Jack_6.35mm_Neutrik_NMJ6HFD2_Horizontal
J603: Interconnect; IDC-Header_2x04_P2.54mm_Horizontal
JP601: GND_JMP; SolderJumper-2_P1.3mm_Open_TrianglePad1.0x1.5mm
JP602: Phant. Pwr; PinHeader_1x02_P2.54mm_Vertical
R601, R607: 1K 1%; R_0805_2012Metric_Pad1.20x1.40mm_HandSolder
R602, R608: 39K 1%; R_0603_1608Metric_Pad0.98x0.95mm_HandSolder
R603, R605: 6.8K 1%; R_0805_2012Metric_Pad1.20x1.40mm_HandSolder
R604: 27K 1%; R_0805_2012Metric_Pad1.20x1.40mm_HandSolder
R606, R611: 39K; R_0603_1608Metric_Pad0.98x0.95mm_HandSolder
R609, R610: 10K; R_0805_2012Metric_Pad1.20x1.40mm_HandSolder
RV601: 50K log.; Potentiometer_Alps_RK09K_Single_Horizontal
TP601: Phantom Power; TestPoint_THTPad_D2.5mm_Drill1.2mm
U601: NE5534; SOIC-8_3.9x4.9mm_P1.27mm
U602: TPA6111A2; SOIC-8_3.9x4.9mm_P1.27mm

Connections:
+5V: C602.1, C604.1, J603.4, U602.8 (VDD)
+15V: C612.1, J603.2, U601.7 (V+)
-15V: C603.2, J603.3, U601.4 (V-)
/Headphone: J603.8, RV601.3
/MicPre: C601.2, J603.6, R602.2, U601.6
GND: C602.2, C603.1, C604.2, C607.2, C609.2, C612.2, D601.2 (A), D602.1 (K), D603.1 (K), D604.2 (A), J601.1, J602.S, J602.SN, J603.1, J603.5, J603.7, JP601.1 (A), R608.1, RV601.1, U602.4 (GND), U602.5 (SHDN)
GNDREF: J601.G, JP601.2 (B)
unnamed: C605.1, J601.2, R603.2
unnamed: C606.2, J602.R, J602.RN
unnamed: C608.2, J602.T, J602.TN
unnamed: C610.1, J601.3, R605.1
unnamed: C611.1, R610.1
unnamed: C611.2, C614.2, RV601.2
unnamed: C614.1, R609.1
unnamed: C605.2, D601.1 (K), D602.2 (A), R601.2
unnamed: C610.2, D603.2 (A), D604.1 (K), R607.2
unnamed: JP602.1 (A), TP601.1
unnamed: R604.2, R607.1, R608.2, U601.3 (+)
unnamed: C601.1, R601.1, R602.1, R604.1, U601.2 (-)
unnamed: C609.1, U602.3 (BYPASS)
unnamed: R606.1, R610.2, U602.2 (IN1-)
unnamed: R609.2, R611.2, U602.6 (IN2-)
unnamed: C608.1, R606.2, U602.1 (VO1)
unnamed: C606.1, R611.1, U602.7 (VO2)
V_Phant: C607.1, JP602.2 (B), R603.1, R605.2

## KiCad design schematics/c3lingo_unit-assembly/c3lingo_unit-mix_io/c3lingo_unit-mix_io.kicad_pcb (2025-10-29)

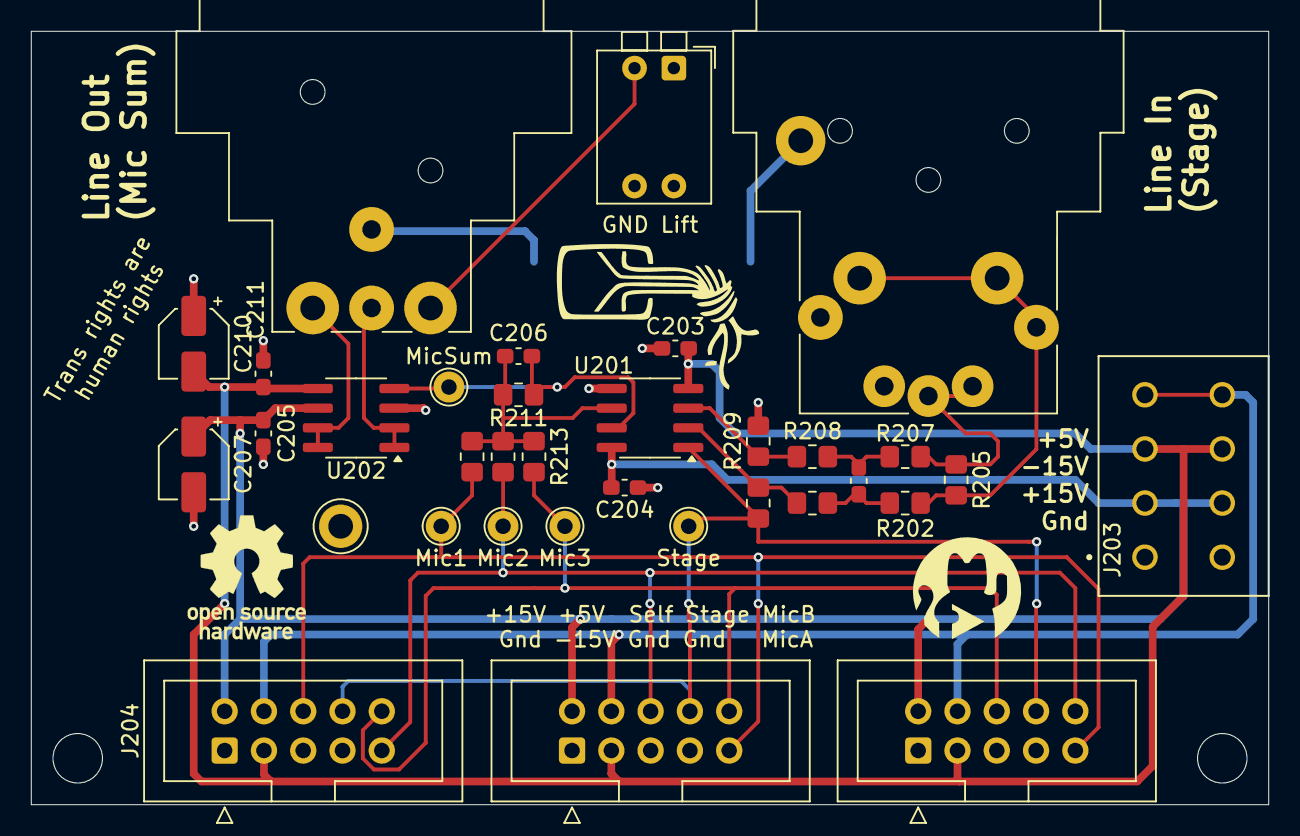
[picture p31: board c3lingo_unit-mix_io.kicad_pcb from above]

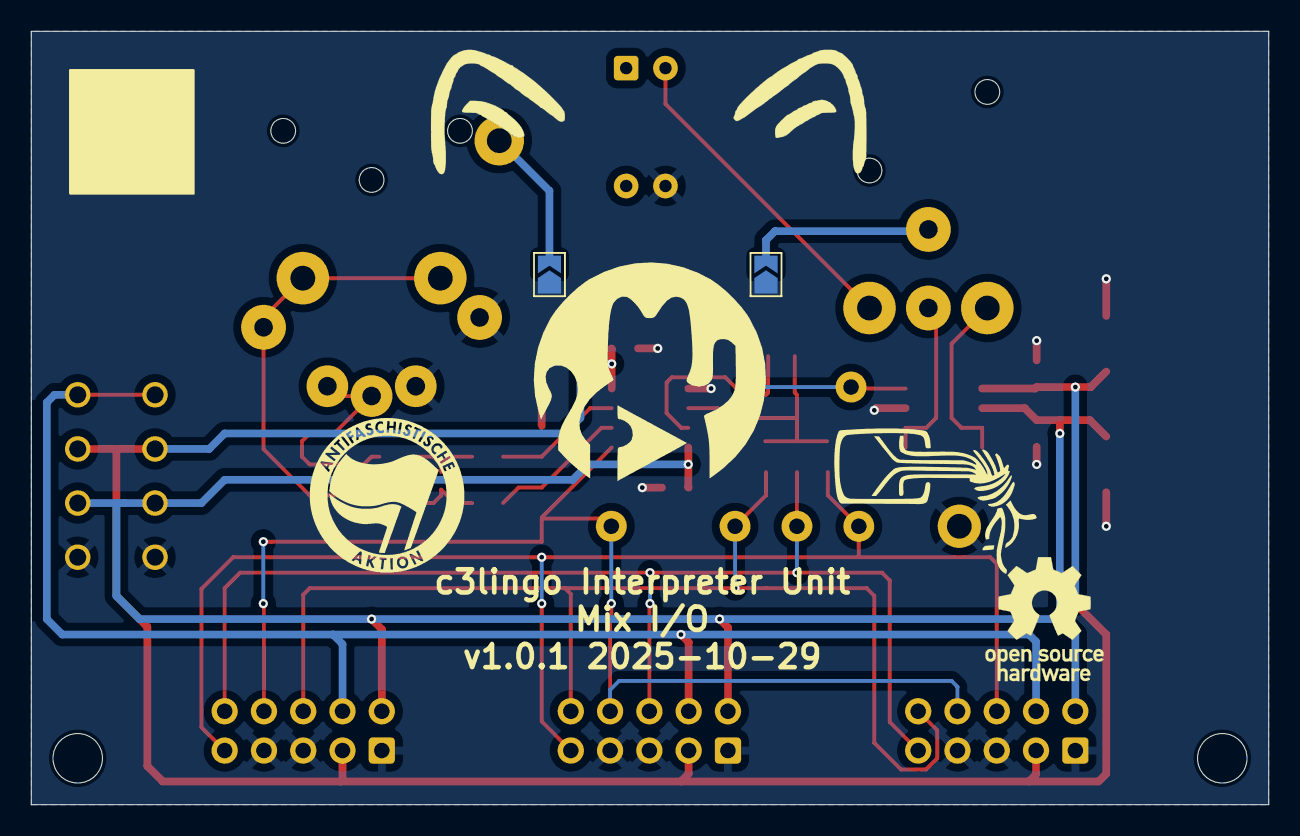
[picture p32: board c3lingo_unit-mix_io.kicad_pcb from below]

Board: 2 copper layers, 80.0 x 50.0 mm, 38 parts (2 on the bottom side), 20 nets.

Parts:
C202: 220pF; C_0603_1608Metric_Pad1.08x0.95mm_HandSolder
C203, C204, C205, C211: 100nF; C_0603_1608Metric_Pad1.08x0.95mm_HandSolder
C206: 22pF; C_0603_1608Metric_Pad1.08x0.95mm_HandSolder
C207, C210: 10uF; CP_Elec_4x5.4
H201, H202: MountingHole; MountingHole_3.2mm_M3
J201: Stage Line-In; Jack_XLR-6.35mm_Neutrik_NCJ6FA-H_Horizontal
J202: Mix Line-Out; Jack_XLR_Neutrik_NC3MAAH_Horizontal
J203: PowerSupply; TerminalBlock_Phoenix_SPTAF-1-4-3.5_1x04_P3.5mm
J204: Ch1; IDC-Header_2x05_P2.54mm_Vertical
J205: Ch2; IDC-Header_2x05_P2.54mm_Vertical
J206: Ch3; IDC-Header_2x05_P2.54mm_Vertical
JP201, JP202: GND_JMP; SolderJumper-2_P1.3mm_Open_TrianglePad1.0x1.5mm
R201, R202, R203, R207, R208, R209, R211: 10K; R_0805_2012Metric_Pad1.20x1.40mm_HandSolder
R205: 3.3K; R_0805_2012Metric_Pad1.20x1.40mm_HandSolder
R210, R212, R213: 22K; R_0805_2012Metric_Pad1.20x1.40mm_HandSolder
SW201: GND Lift; SW_DIP_SPSTx02_Piano_CTS_Series194-2MSTN_W7.62mm_P2.54mm
TP201: Stage; TestPoint_THTPad_D2.0mm_Drill1.0mm
TP202: Mic1; TestPoint_THTPad_D2.0mm_Drill1.0mm
TP203: Mic2; TestPoint_THTPad_D2.0mm_Drill1.0mm
TP204: MicSum; TestPoint_THTPad_D2.0mm_Drill1.0mm
TP205: Mic3; TestPoint_THTPad_D2.0mm_Drill1.0mm
TP206: GND; TestPoint_Keystone_5005-5009_Compact
U201: LM833-N; SOIC-8_3.9x4.9mm_P1.27mm
U202: DRV135UA; SOIC-8_3.9x4.9mm_P1.27mm

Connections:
+5V: J203.4, J204.4, J205.4, J206.4
+15V: C204.2, C205.1, C207.1, J203.2, J204.2, J205.2, J206.2, U201.8 (V+), U202.6 (V+)
-15V: C203.2, C210.2, C211.1, J203.3, J204.3, J205.3, J206.3, U201.4 (V-), U202.5 (V-)
/Mic_Ch1: J204.6, J205.9, J206.9, R210.2, TP202.1
/Mic_Ch2: J204.9, J205.6, J206.10, R212.2, TP203.1
/Mic_Ch3: J204.10, J205.10, J206.6, R213.2, TP205.1
/Stage: J204.8, J205.8, J206.8, R201.1, TP201.1, U201.1
GND: C203.1, C204.1, C205.2, C207.2, C210.1, C211.2, J201.1, J201.S, J203.1, J204.1, J204.5, J204.7, J205.1, J205.5, J205.7, J206.1, J206.5, J206.7, JP201.1 (A), JP202.1 (A), R209.2, SW201.3, TP206.1, U201.5 (+), U202.3 (GND)
GNDREF: J201.G, J202.G, JP201.2 (B), JP202.2 (B)
unnamed: C202.1, R202.2, R203.2
unnamed: C202.2, R207.2, R208.2
unnamed: J201.2, J201.T, R202.1, R205.2
unnamed: J201.3, J201.R, R205.1, R207.1
unnamed: J202.1, SW201.2
unnamed: R208.1, R209.1, U201.3 (+)
unnamed: R201.2, R203.1, U201.2 (-)
unnamed: C206.2, R210.1, R211.2, R212.1, R213.1, U201.6 (-)
unnamed: J202.2, U202.7 (SENSE+), U202.8 (VO+)
unnamed: J202.3, U202.1 (VO-), U202.2 (SENSE-)
unnamed: C206.1, R211.1, TP204.1, U201.7, U202.4 (VIN)

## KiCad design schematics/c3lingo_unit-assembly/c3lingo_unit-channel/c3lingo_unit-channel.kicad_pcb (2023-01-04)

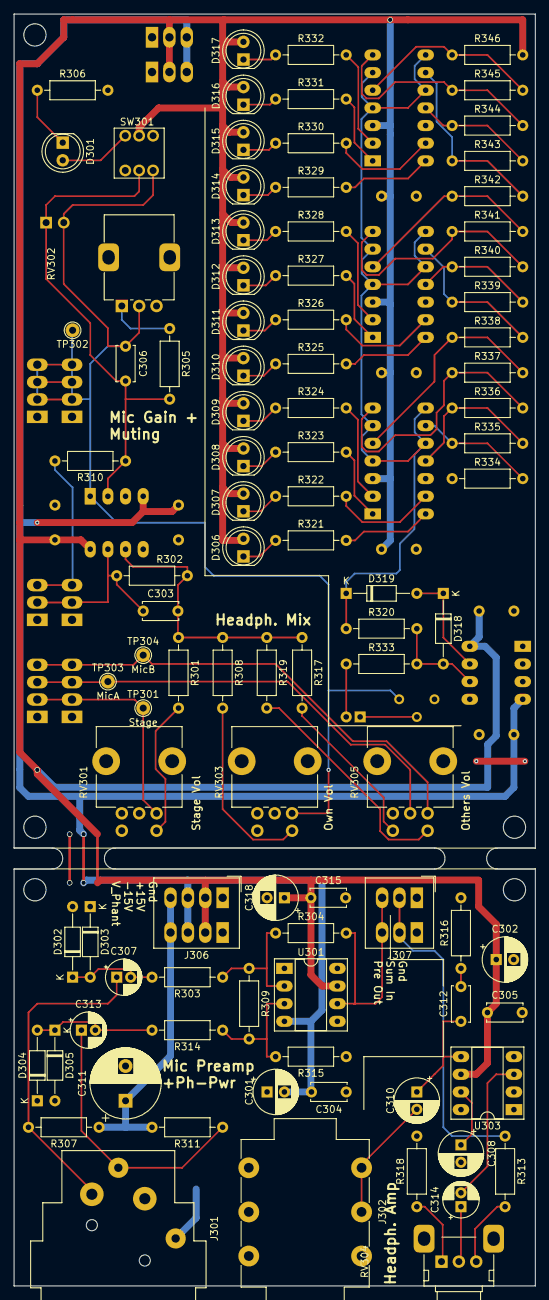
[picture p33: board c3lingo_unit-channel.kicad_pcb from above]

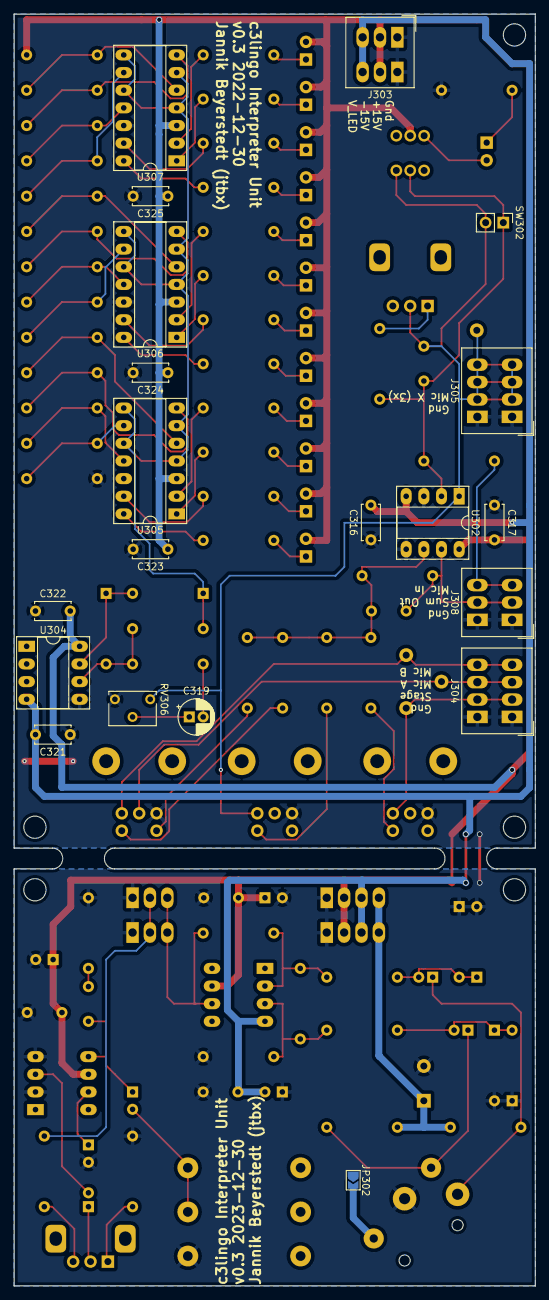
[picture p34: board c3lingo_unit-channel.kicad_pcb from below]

Board: 2 copper layers, 75.0 x 183.0 mm, 120 parts (20 on the bottom side), 77 nets.

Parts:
C301, C302, C308, C318: 100uF; CP_Radial_D6.3mm_P2.50mm
C303: 22pF; C_Disc_D5.0mm_W2.5mm_P5.00mm
C304, C305, C306, C315, C316, C317, C321, C322, C323, C324, C325: 100nF; C_Disc_D5.0mm_W2.5mm_P5.00mm
C307, C313: 1uF/ 63V lowESR; CP_Radial_D5.0mm_P2.00mm
C310: 220uF lowESR; CP_Radial_D6.3mm_P2.50mm
C311: 100uF/ 63V; CP_Radial_D10.0mm_P5.00mm
C312: 47nF; C_Disc_D5.0mm_W2.5mm_P5.00mm
C314, C319: 1uF; CP_Radial_D5.0mm_P2.00mm
D301: On-Air (rd); LED_D5.0mm
D302, D303, D304, D305, D318, D319: 1N4148; D_DO-35_SOD27_P10.16mm_Horizontal
D306, D307, D308, D309, D317: rd; LED_D5.0mm
D310, D311, D315, D316: ye; LED_D5.0mm
D312, D313, D314: gn; LED_D5.0mm
H301, H302, H303, H305, H306: MountingHole; MountingHole_3.2mm_M3
J301: Mic X In; Jack_XLR_Neutrik_NC3FAAH2_Horizontal
J302: Headphone X; Jack_6.35mm_Neutrik_NMJ6HFD2_Horizontal
J303: PowerSupply; TerminalBlock_Phoenix_PTSM-0,5-3-2.5-H-THR_1x03_P2.50mm_Hor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
J304: Inputs; TerminalBlock_Phoenix_PTSM-0,5-4-2.5-H-THR_1x04_P2.50mm_Hor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
J305: Output; TerminalBlock_Phoenix_PTSM-0,5-4-2.5-H-THR_1x04_P2.50mm_Hor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
J306: PowerSupply; TerminalBlock_Phoenix_PTSM-0,5-4-2.5-H-THR_1x04_P2.50mm_Hor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
J307, J308: Interconnect; TerminalBlock_Phoenix_PTSM-0,5-3-2.5-H-THR_1x03_P2.50mm_Hor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
JP302: GND_JMP; SolderJumper-2_P1.3mm_Open_TrianglePad1.0x1.5mm
R301, R302, R308, R317, R319: 22K; R_Axial_DIN0207_L6.3mm_D2.5mm_P10.16mm_Horizontal
R303, R314: 1K 1%; R_Axial_DIN0207_L6.3mm_D2.5mm_P10.16mm_Horizontal
R304, R315: 330K 1%; R_Axial_DIN0207_L6.3mm_D2.5mm_P10.16mm_Horizontal
R305: 56R; R_Axial_DIN0207_L6.3mm_D2.5mm_P10.16mm_Horizontal
R306, R341: 680R; R_Axial_DIN0207_L6.3mm_D2.5mm_P10.16mm_Horizontal
R307, R311: 6.8K 1%; R_Axial_DIN0207_L6.3mm_D2.5mm_P10.16mm_Horizontal
R309: 27K 1%; R_Axial_DIN0207_L6.3mm_D2.5mm_P10.16mm_Horizontal
R310: 330R; R_Axial_DIN0207_L6.3mm_D2.5mm_P10.16mm_Horizontal
R313: 330K; R_Axial_DIN0207_L6.3mm_D2.5mm_P10.16mm_Horizontal
R316: 12R; R_Axial_DIN0207_L6.3mm_D2.5mm_P10.16mm_Horizontal
R318: 2.2K; R_Axial_DIN0207_L6.3mm_D2.5mm_P10.16mm_Horizontal
R320: 15K; R_Axial_DIN0207_L6.3mm_D2.5mm_P10.16mm_Horizontal
R321, R322, R323, R324, R325, R326, R327, R328, R329, R330, R331, R332, R340: 390R; R_Axial_DIN0207_L6.3mm_D2.5mm_P10.16mm_Horizontal
R333, R342: 1K; R_Axial_DIN0207_L6.3mm_D2.5mm_P10.16mm_Horizontal
R334, R336: 68R; R_Axial_DIN0207_L6.3mm_D2.5mm_P10.16mm_Horizontal
R335: 39R; R_Axial_DIN0207_L6.3mm_D2.5mm_P10.16mm_Horizontal
R337: 100R; R_Axial_DIN0207_L6.3mm_D2.5mm_P10.16mm_Horizontal
R338: 150R; R_Axial_DIN0207_L6.3mm_D2.5mm_P10.16mm_Horizontal
R339: 270R; R_Axial_DIN0207_L6.3mm_D2.5mm_P10.16mm_Horizontal
R343: 1.5K; R_Axial_DIN0207_L6.3mm_D2.5mm_P10.16mm_Horizontal
R344, R346: 2.7K; R_Axial_DIN0207_L6.3mm_D2.5mm_P10.16mm_Horizontal
R345: 3.9K; R_Axial_DIN0207_L6.3mm_D2.5mm_P10.16mm_Horizontal
RV301, RV303: 50K log.; Potentiometer_Alps_RK09K_Double_Vertical
RV302: 10K log.; Potentiometer_Alps_RK09K_Single_Vertical
RV304: 50K log.; Potentiometer_Alps_RK09K_Single_Horizontal
RV305: 50K log. st.; Potentiometer_Alps_RK09K_Double_Vertical
RV306: 50K; Potentiometer_Vishay_T73XX_Horizontal
SW301: OnAir_X; SW_APEM_MHPS2273_DPDT
SW302: Mute_X; PinHeader_1x02_P2.54mm_Vertical
TP301: Stage; TestPoint_THTPad_D2.0mm_Drill1.0mm
TP302: MicX; TestPoint_THTPad_D2.0mm_Drill1.0mm
TP303: MicA; TestPoint_THTPad_D2.0mm_Drill1.0mm
TP304: MicB; TestPoint_THTPad_D2.0mm_Drill1.0mm
U301: NE5534; DIP-8_W7.62mm_Socket_LongPads
U302, U304: LM833N; DIP-8_W7.62mm_Socket_LongPads
U303: LM386N-4; DIP-8_W7.62mm_Socket_LongPads
U305, U306, U307: LM339; DIP-14_W7.62mm_Socket_LongPads

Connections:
+15V: C302.1, C305.1, C315.1, C317.2, C318.1, C322.2, C323.1, C324.1, C325.1, D306.2 (A), D307.2 (A), D308.2 (A), D309.2 (A), D310.2 (A), D311.2 (A), D312.2 (A), D313.2 (A), D314.2 (A), D315.2 (A), D316.2 (A), D317.2 (A), J303.2, J306.2, R346.2, SW301.5 (B), U301.7 (V+), U302.8 (V+), U303.6 (V+), U304.8 (V+), U305.3 (V+), U306.3 (V+), U307.3 (V+)
-15V: C301.2, C304.2, C316.2, C321.2, J303.3, J306.3, U301.4 (V-), U302.4 (V-), U304.4 (V-)
/Monitor_OthersA: J304.3, RV305.6, TP303.1
/Monitor_OthersB: J304.4, RV305.3, TP304.1
/Monitor_Stage: J304.2, RV301.3, TP301.1
/PreampOut: C306.1, J305.2, J305.3, J305.4, RV302.2, RV303.3, RV306.1, SW301.1 (A), SW302.2, TP302.1, U302.1
AmpIn: J307.2, R313.1
GND: C301.1, C302.2, C304.1, C305.2, C308.2, C311.2, C315.2, C316.1, C317.1, C318.2, C321.1, C322.1, C323.2, C324.2, C325.2, D302.2 (A), D303.1 (K), D304.1 (K), D305.2 (A), J301.1, J302.S, J303.1, J304.1, J305.1, J306.1, J307.1, J308.1, JP302.1 (A), R306.2, R315.1, R316.2, R318.2, R334.1, RV301.1, RV303.1, RV305.1, RV306.3, U302.3 (+), U302.5 (+), U303.2 (-), U303.4 (GND), U304.5 (+), U305.12 (V-), U306.12 (V-), U307.12 (V-)
GNDREF: J301.G, JP302.2 (B)
MicGainIn: J308.3, R310.2
MicPreOut: J307.3, R304.2, U301.6
unnamed: C303.2, R301.1, R302.2, R308.1, R317.1, R319.1, U302.6 (-)
unnamed: C306.2, R305.2, R310.1, SW301.2 (B), SW302.1, U302.2 (-)
unnamed: C307.1, J301.2, R307.2
unnamed: C307.2, D302.1 (K), D303.2 (A), R303.2
unnamed: C308.1, U303.7 (BYPASS)
unnamed: C310.1, C312.1, U303.5
unnamed: C310.2, J302.R, J302.T
unnamed: C312.2, R316.1
unnamed: C313.1, J301.3, R311.1
unnamed: C313.2, D304.2 (A), D305.1 (K), R314.2
unnamed: C314.1, RV304.2
unnamed: C314.2, U303.3 (+)
unnamed: C319.1, RV306.2
unnamed: C319.2, R333.1
unnamed: D301.1 (K), R306.1
unnamed: D301.2 (A), SW301.6 (C)
unnamed: D306.1 (K), R321.1
unnamed: D307.1 (K), R322.1
unnamed: D308.1 (K), R323.1
unnamed: D309.1 (K), R324.1
unnamed: D310.1 (K), R325.1
unnamed: D311.1 (K), R326.1
unnamed: D312.1 (K), R327.1
unnamed: D313.1 (K), R328.1
unnamed: D314.1 (K), R329.1
unnamed: D315.1 (K), R330.1
unnamed: D316.1 (K), R331.1
unnamed: D317.1 (K), R332.1
unnamed: D318.1 (K), D319.2 (A), U304.7
unnamed: D318.2 (A), R320.2, R333.2, U304.6 (-)
unnamed: D319.1 (K), R320.1, U305.4 (-), U305.6 (-), U305.8 (-), U305.10 (-), U306.4 (-), U306.6 (-), U306.8 (-), U306.10 (-), U307.4 (-), U307.6 (-), U307.8 (-), U307.10 (-)
unnamed: R301.2, RV301.2
unnamed: R303.1, R304.1, R309.1, U301.2 (-)
unnamed: R305.1, RV302.1
unnamed: R308.2, RV303.2
unnamed: R309.2, R314.1, R315.2, U301.3 (+)
unnamed: R313.2, RV304.3
unnamed: R317.2, RV305.5
unnamed: R318.1, RV304.1
unnamed: R319.2, RV305.2
unnamed: R321.2, U305.14
unnamed: R322.2, U305.13
unnamed: R323.2, U305.1
unnamed: R324.2, U305.2
unnamed: R325.2, U306.14
unnamed: R326.2, U306.13
unnamed: R327.2, U306.1
unnamed: R328.2, U306.2
unnamed: R329.2, U307.14
unnamed: R330.2, U307.13
unnamed: R331.2, U307.1
unnamed: R332.2, U307.2
unnamed: R334.2, R335.1, U305.9 (+)
unnamed: R335.2, R336.1, U305.11 (+)
unnamed: R336.2, R337.1, U305.7 (+)
unnamed: R337.2, R338.1, U305.5 (+)
unnamed: R338.2, R339.1, U306.9 (+)
unnamed: R339.2, R340.1, U306.11 (+)
unnamed: R340.2, R341.1, U306.7 (+)
unnamed: R341.2, R342.1, U306.5 (+)
unnamed: R342.2, R343.1, U307.9 (+)
unnamed: R343.2, R344.1, U307.11 (+)
unnamed: R344.2, R345.1, U307.7 (+)
unnamed: R345.2, R346.1, U307.5 (+)
SumOut: C303.1, J308.2, R302.1, U302.7
V_Phant: C311.1, J306.4, R307.1, R311.2

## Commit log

2020-10-12 Schematic: Proof of concept (one microphone)
    [c3lingo-interpreter-unit.kicad_pcb, c3lingo-interpreter-unit.sch]
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2020-11-02 Schematic: Bugfixes, VU meter draft, first development PCB draft
    [c3lingo-interpreter-unit.kicad_pcb, c3lingo-interpreter-unit.sch, vu_meter.sch]
2020-11-09 Move VU-Meter to own project
    [c3lingo-interpreter-unit.kicad_pcb, c3lingo-interpreter-unit.sch, vu_meter.kicad_pcb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]
2020-11-09 Schematic Main: Add corrected headphone amp
    [c3lingo-interpreter-unit.kicad_pcb, c3lingo-interpreter-unit.sch, vu_meter.kicad_pcb]
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2020-11-12 Refine headphone mix requirements, fix signal flow
    [c3lingo-interpreter-unit.kicad_pcb, c3lingo-interpreter-unit.sch]
2020-11-12 final fixes for first prototype PCB order
    [c3lingo-interpreter-unit.kicad_pcb, c3lingo-interpreter-unit.sch, vu_meter.kicad_pcb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]
2020-12-13 VU meter: add -15V, fix footprints, specify LED resistors
    TODO: Decide on signal smoothing
    [vu_meter.kicad_pcb, vu_meter.sch]
2020-12-13 Main: Summing design flaw fixed; better headphone vol. range
    - Multiple R and C value adaptions
    - Line Input: No relevant difference between INA134 and own circuit -> LM833 chosen
    - Signal busses/ summing module inputs fixed
    - TODO: On-Air Button
    - TODO: Update PCB layout
    [c3lingo-interpreter-unit.kicad_pcb, c3lingo-interpreter-unit.sch]
2020-12-13 Main: Add 15V phantom power
    [c3lingo-interpreter-unit.kicad_pcb, c3lingo-interpreter-unit.sch, vu_meter.kicad_pcb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]
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2021-04-17 [DOC] reworked button/ switch options
2021-05-22 [DOC] Add some data sheets
    [Neutrik-nc3maah.dxf, Neutrik-ncj6fa-h-da.dxf, NeutrikRean-nys216.dxf]
2021-05-23 [TIDY] Split old design in new hierarchal layout
    TODO: Shrink channel strip to A4 paper size, integrate VU meter
    [c3lingo_unit-assembly.kicad_pcb, c3lingo_unit-assembly.sch, c3lingo_unit-channel.kicad_pcb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]
2021-05-23 [TIDY] Channel Strip: Integrate VU Meter
    [c3lingo_unit-assembly.sch, c3lingo_unit-channel.sch, c3lingo_unit-mix_io.sch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]
2021-05-30 Schematics: Add missing functionality, add footprints, fix todos
    - Add On-Air button
    - Lower frequency for the input HPF
    - (final) button footprints
    - (final) potentiometer values and footprints
    [c3lingo_unit-assembly.kicad_pcb, c3lingo_unit-assembly.sch, c3lingo_unit-channel.sch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]
2021-06-02 PCB: Line in/out and mics summing design
    [c3lingo_unit-mix_io.kicad_pcb, c3lingo_unit-mix_io.sch]
2021-06-02 PCB: Channel strip design
    [c3lingo_unit-channel.kicad_pcb, c3lingo_unit-channel.sch]
2021-06-03 [DOC] Add BOM with some approx. prices
    [Neutrik-ncj6fa-h-da.dxf]
2021-09-02 [TIDY] remove old VU meter project
    [vu_meter.kicad_pcb, vu_meter.sch]
2021-09-05 [FIX] Schematics: Revised values and PCB errata text
    * fixed trim pot range at VU meter
    * TODOs removed (5V V_LED didn't work out, 10uF at LM386 wasn't better, VU meter filtering not needed)
    * phantom power voltage changed and readme chapter added
    * hardware errata: gain pot. pins are swapped, ground plane isn't fully connected
    Footprints and PCB aren't fixed to keep the schematic compatible with the existing PCBs!
    [c3lingo_unit-assembly.sch, c3lingo_unit-channel.sch, c3lingo_unit-mix_io.sch]
2022-12-04 Upgrade project to KiCad 6
    Item annotations were re-generated as there were duplicate items otherwise somehow. This means, that some item numbers have changed!
    [c3lingo_unit-assembly.kicad_sch, c3lingo_unit-assembly.sch, c3lingo_unit-channel.kicad_pcb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]
2022-12-30 KiCad 6: Update power flag symbols
    Power flags were updated in the new KiCad 6 library, which was a warning in the ERC.
    [c3lingo_unit-assembly.kicad_sch, c3lingo_unit-channel.kicad_sch, c3lingo_unit-mix_io.kicad_pcb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]
2023-01-04 Fix 3D model paths for KiCad 6
    [c3lingo_unit-channel.kicad_pcb, c3lingo_unit-mix_io.kicad_pcb]
2023-01-04 Schematics: Fix multiple issues with initial prototype
    - Removed high-pass filter between microphone pre-amp and gain as it made things sound worse
    - Removed low-pass filter before VU meter as it looked fine without
    - Connect VU meter to +15 V directly as 5 V didn't work
    - Footprint of the gain potentiometer (Alps RK09) seems to be fixed with the KiCad 6 library
    [c3lingo_unit-assembly.kicad_sch, c3lingo_unit-channel.kicad_sch, c3lingo_unit-mix_io.kicad_sch]
2023-01-04 PCB: Update for new schematic (still THT for now)
    [c3lingo_unit-channel.kicad_pcb, c3lingo_unit-mix_io.kicad_pcb]
2023-01-04 Update footprints to KiCad 6
    [c3lingo_unit-channel.kicad_pcb, c3lingo_unit-mix_io.kicad_pcb]
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2023-01-15 [TIDY] Split channel into two schematics
    [c3lingo_unit-assembly.kicad_sch, c3lingo_unit-channel_io.kicad_pcb, c3lingo_unit-channel_io.kicad_sch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]
2024-02-23 Update to KiCad 7
    [c3lingo_unit-assembly.kicad_sch, c3lingo_unit-channel_io.kicad_pcb, c3lingo_unit-channel_io.kicad_sch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]
2024-03-04 new headphone amp IC (board layout not updated)
    [c3lingo_unit-assembly.kicad_sch, c3lingo_unit-channel_io.kicad_sch, c3lingo_unit-channel_mixer.kicad_sch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]
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2024-06-30 Reworks board-to-board connections
    Instead of having connections between all boards, use the mix_io board as an audio signal distribution hub.
    Note: PCB not updated
    [c3lingo_unit-assembly.kicad_sch, c3lingo_unit-channel_io.kicad_sch, c3lingo_unit-channel_mixer.kicad_sch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]
2024-07-06 Re-layout boards with SMD components
    * Channel Mix: Removed vu meter potentiometer as good setting was found (10 dB
    more headroom)
    * Channel Mix: Add vu meter alternate power
    * Channel I/O: Added jumper for phantom power enable/disable
    * Add GND test points
    [c3lingo_unit-assembly.kicad_sch, c3lingo_unit-channel_io.kicad_pcb, c3lingo_unit-channel_io.kicad_sch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]
2024-07-07 Fix date on PCB dimensions PDF
    [c3lingo_unit-mix_io.kicad_pcb, c3lingo_unit-mix_io.kicad_sch]
2024-07-07 Channel-Mix: Rework LED supply voltage
    [c3lingo_unit-assembly.kicad_sch, c3lingo_unit-channel_io.kicad_pcb, c3lingo_unit-channel_io.kicad_sch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]
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2024-07-11 Channel I/O: Fix headphone amp caps, re-phrase readme section
    [c3lingo_unit-channel_io.kicad_pcb, c3lingo_unit-channel_io.kicad_sch]
2024-07-11 Channel Mixer: Fix LP filter at mic gain
    1nF has about 15kHz cutoff frequency at full gain
    [c3lingo_unit-channel_mixer.kicad_pcb, c3lingo_unit-channel_mixer.kicad_sch]
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2024-08-18 Channel Mixer: Add LP filter to V/U meter
    Note: schematic and dimenstions PDFs not updated as more changes come
    To reduce HF noise on the power rail introduced by the switching of the comperators
    [c3lingo_unit-channel_mixer.kicad_pcb, c3lingo_unit-channel_mixer.kicad_sch]
2024-09-06 Channel Mixer: Rework muting mechanism
    Note: Schematic PDF not updated yet
    [c3lingo_unit-assembly.kicad_sch, c3lingo_unit-channel_io.kicad_pcb, c3lingo_unit-channel_io.kicad_sch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]
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2024-09-12 Move potentiometers down, fix JLC PCB components
    - Fix JLC PCB component orientation
    - Add do-not-populate to all THD components
    - Fix JLC part selection, tweak values to be standard components
    [c3lingo_unit-assembly.kicad_sch, c3lingo_unit-channel_io.kicad_pcb, c3lingo_unit-channel_io.kicad_sch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]
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2024-11-21 Add rework to fix VU meter, muting delay, LP filters
    Note: PCB files were not upated!
    Changes/ required manual rework:
    - Replace C314 with 100nF to reduce muting fade time
    - Replace C301 with 680pF to have a 12 kHz low-pass filter on headphones
    - Replace R309, R232, R335 to fix VU meter range (steps are a bit wonky
    afterwards, but top (and bottom) range are a lot more save now)
    - Add 220pF in parallel to R602 to have a 10 kHz low-pass on microphone input
    More rework is optional:
    - Replace RV201 with a 10k (fixed) resistor (adjustment is not necessary)
    - Replace R303 with 1k to reduce gain range from 45 to 34dB
    [c3lingo_unit-assembly.kicad_sch, c3lingo_unit-channel_io.kicad_sch, c3lingo_unit-channel_mixer.kicad_sch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]
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2024-12-18 Add 3D models for connectors and potis
    Used Alps RK09L1140 instead of CUI PTN09X as I haven't found a model for the actual part and the other one has the same dimensions.
    Also the axle in the model for the Alps RK09K is probably too long.
    [c3lingo_unit-channel_io.kicad_pcb, c3lingo_unit-channel_mixer.kicad_pcb, c3lingo_unit-mix_io.kicad_pcb]
2025-08-26 Channel Mixer: Reduce mic and output gain
    Note: Schematics not re-exported!
    [c3lingo_unit-assembly.kicad_sch, c3lingo_unit-channel_io.kicad_sch, c3lingo_unit-channel_mixer.kicad_sch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]
2025-08-26 Channel Mixer: Re-design VU meter scale
    Note: Schematic not re-exported!
    [c3lingo_unit-channel_mixer.kicad_sch]
2025-08-26 Line I/O: Remove gain adjustment (PCB not updated!)
    Tweaking the line input gain is not necessary as the users will adjust the volume to personal preference anyways.
    Note: PCB not updated!
    [c3lingo_unit-mix_io.kicad_sch]
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2025-08-26 Channel-Mixer: Change VU meter LEDs footprint to 5x2mm THD
    [c3lingo_unit-channel_mixer.kicad_pcb, c3lingo_unit-channel_mixer.kicad_sch]
2025-08-26 Line I/O: Optimize Schematic and update PCB
    Share one LM833 instead of only using one half for summing and line input each.
    [c3lingo_unit-mix_io.kicad_pcb, c3lingo_unit-mix_io.kicad_sch]
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2025-08-26 Refactor: Rename component rotation
    The latest release of the (JLC PCB) Fabrication Toolkit plugin needs the rotation offset field to be named "FT Rotation Offset"
    [c3lingo_unit-channel_io.kicad_pcb, c3lingo_unit-channel_io.kicad_sch, c3lingo_unit-channel_mixer.kicad_pcb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]
2025-08-26 Channel I/O: Mark phantom power testpoint as DNP
    It's just a footprint to solder a wire on and no component to populate.
    [c3lingo_unit-channel_io.kicad_pcb, c3lingo_unit-channel_io.kicad_sch]
2025-08-30 Channel I/O: Fix value of C601
    [c3lingo_unit-assembly.kicad_sch, c3lingo_unit-channel_io.kicad_pcb, c3lingo_unit-channel_io.kicad_sch]
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2025-09-08 Line I/O: Fix polarity of C210
    [c3lingo_unit-assembly.kicad_sch, c3lingo_unit-mix_io.kicad_pcb, c3lingo_unit-mix_io.kicad_sch]
2025-09-08 Channel-Mixer: Fix silkscreen label of TP305
    [c3lingo_unit-channel_mixer.kicad_pcb]
2025-09-19 Channel-Mixer: Replace mute-button connector
    [c3lingo_unit-channel_mixer.kicad_pcb, c3lingo_unit-channel_mixer.kicad_sch]
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2025-09-29 PCBs: Fix 3D models, add model for on/off switch
    [Jack_6.35mm_Neutrik_NMJ6HFD2_Horizontal.step, Jack_XLR-6.35mm_Neutrik_NCJ6FA-H_Horizontal.step, Jack_XLR_Neutrik_NC3MAAH_Horizontal.step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]
2025-09-29 Channel-Mixer: Fix position of gain potentiometer
    [c3lingo_unit-channel_mixer.kicad_pcb]
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2025-09-29 Channel-Mixer: Invert mute LED logic (to be an on-air LED)
    [c3lingo_unit-channel_mixer.kicad_pcb, c3lingo_unit-channel_mixer.kicad_sch]
2025-09-29 Channel-Mixer: Add buffer cap for VU meter LEDs
    [c3lingo_unit-channel_mixer.kicad_pcb, c3lingo_unit-channel_mixer.kicad_sch]
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2025-09-29 Channel: Swap mic and headphone signal on IDC connector
    [c3lingo_unit-channel_io.kicad_pcb, c3lingo_unit-channel_io.kicad_sch, c3lingo_unit-channel_mixer.kicad_pcb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]
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2025-10-29 Housing: Add PE connection points and improved ventilation
    [c3lingo-interpreter-unit.FCStd, c3lingo-interpreter-unit_housing.FCStd, c3lingo-interpreter-unit_housing_bottom.FCStd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]
2025-10-29 channel: Select alternate JLCPCB parts
    Some capacitors were not in stock any more, so select some other ones
    [c3lingo_unit-channel_io.kicad_pcb, c3lingo_unit-channel_io.kicad_sch, c3lingo_unit-channel_mixer.kicad_pcb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]
2025-10-29 Channel-Mixer: Fix on-air LED resistor
    [c3lingo_unit-channel_mixer.kicad_pcb, c3lingo_unit-channel_mixer.kicad_sch]
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2026-10-25 WIP FIXUP: Add sketched
    TODO: Make dwg of just the rails
